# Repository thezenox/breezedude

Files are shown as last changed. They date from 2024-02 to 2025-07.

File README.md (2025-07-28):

# BreezeDude
### An Open source low power FANET wind sensor.

Map of almost all wind stations: https://breezedude.de/

For more info and docs see the [Wiki](https://github.com/thezenox/breezedude/wiki)

----
<p align="center">
  <
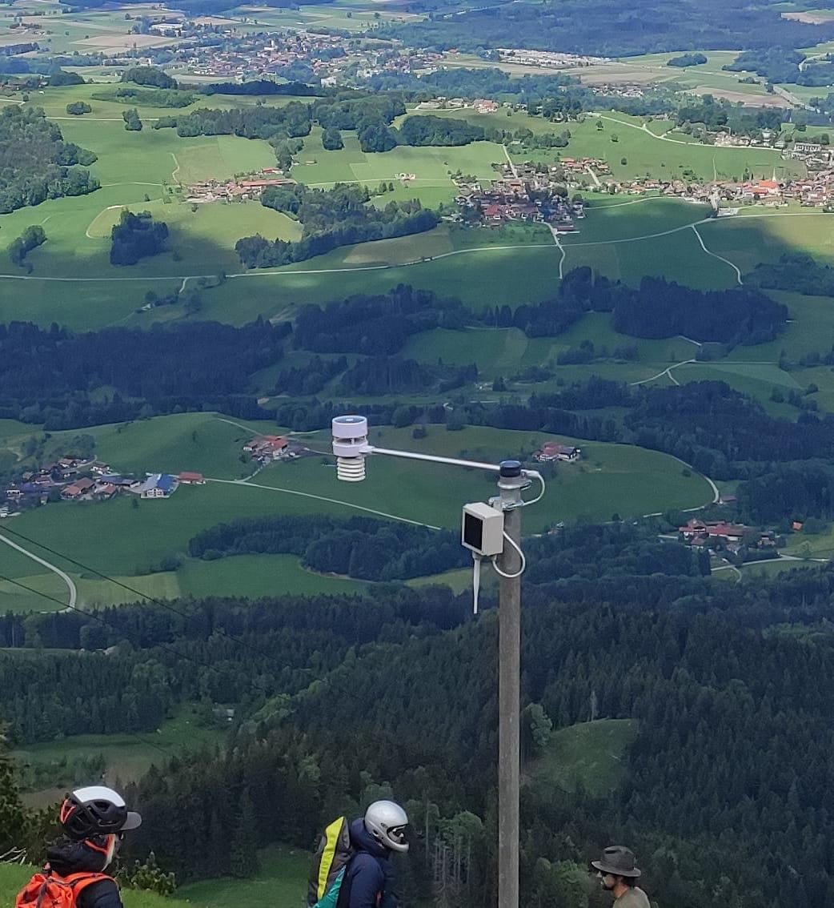
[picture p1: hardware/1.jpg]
  
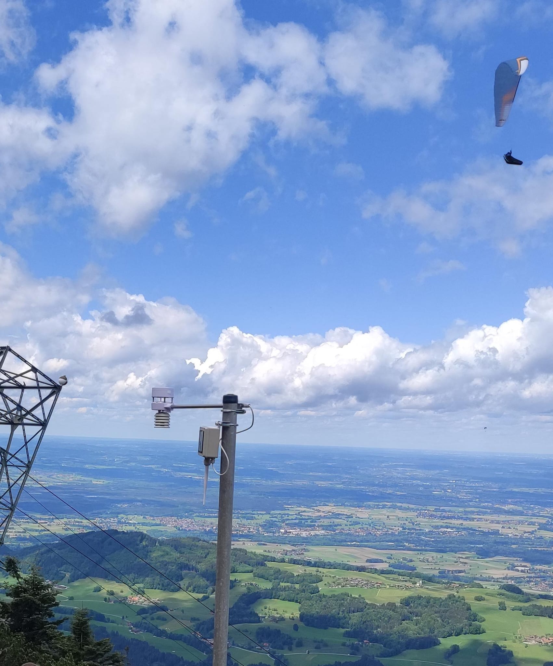
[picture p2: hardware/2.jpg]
   <br>
  <br>
</p>

A low cost FANET wind station using Ecowitt WS80/WS85 ultrasonic or DAVIS 6410 analog sensor.     
USB MSC Settings file and Drag&Drop Firmware upgrade. 

- wind sensor: Ecowitt WS80/WS85 or analog with reed/potentiometer (e.g. DAVIS 6410)
- pressure sensor: HP303B, BMP280, BMP3xx or SPL06-001
- LoRa module: RFM95W (SX1276), G-NiceRF SX1262, LLCC68
- antenna connector: SMA
- microcontroller: SAMD21
- connectivity: USB-C, I2C, 2x UART
- battery: 1S Li-Ion 16340 750mAh (or 1-3x 18650 external)
- solar: 5V
- PCB Size: 53x22mm

Currently using a 60x60 5V solar panel.     
Avg. power consumption at 40s send interval @3.7V battery: 1.2mA with analog sensor, 2.22mA with WS80
 
Based on SMAD21 using [adafruits samd core](https://github.com/adafruit/ArduinoCore-samd) and itsybitsy M0 variant definitions and [bootloader](https://github.com/adafruit/uf2-samdx1).     

#### Related projects and inspiration:
* https://github.com/gereic/GXAirCom
* https://github.com/jgromes/RadioLib
* https://github.com/3s1d/fanet-stm32

If you like this project

<a href="https://www.buymeacoffee.com/thezenox" target="_blank">Buy Me A Landingbeer</a>

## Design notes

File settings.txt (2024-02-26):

#Kommentar

NAME=Teststation

LON=12.345678
LAT=45.678901
ALT=456

HEATER=1
V_HEATER=4.5
V_MPPT=4.8

HEADING_OFFSET=0

BROADCAST_INTERVAL_WEATHER=40
BROADCAST_INTERVAL_NAME=300

SENSOR_BMP280=1
SENSOR_DAVIS6410=0
SENSOR_WS80=1

DEBUG=0
DIV_CPU_SLOW=1
WDT=0

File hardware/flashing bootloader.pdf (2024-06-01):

## Flashing bootloader on factory new SAMD21

### Prerequisites:

- AVR/Microchip Studio
- JTAG programmer (eg. Segger J-Link) + drivers installed
- SAMD21 board (ATSAMD21G18A)

### Programming:

1. Hook up SWD_IO, SWD_CLK and GND of your programmer to the board. Power the board.
2. Start Microchip Studio and open “Device Programming” in Tools.

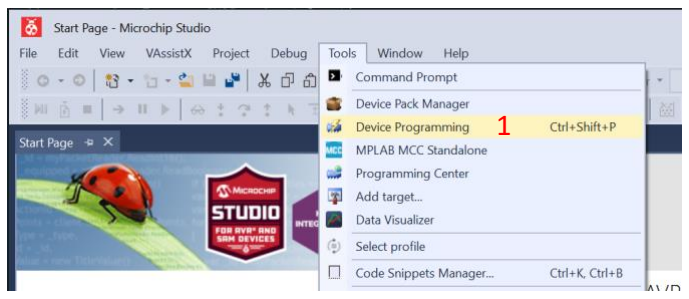
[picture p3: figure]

3. Your programmer should be listed in tools. Select the device type “ATSAMD21G18A” and klick “Apply” and “Read”. The target should be detected.

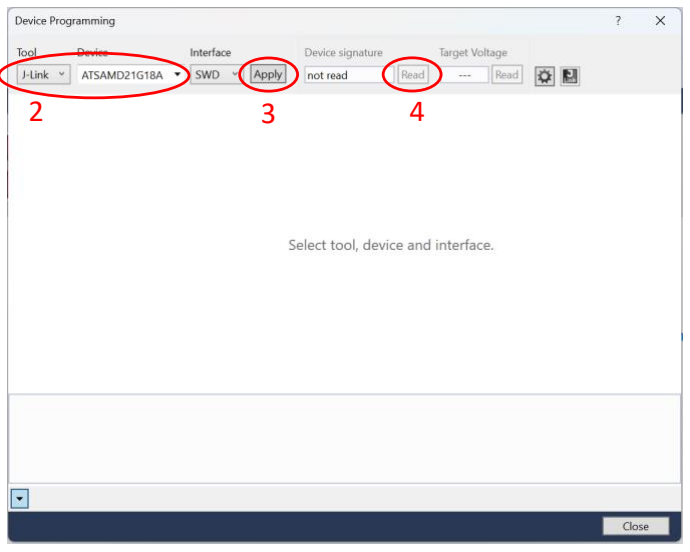
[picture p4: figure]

4. Select “Memories” and klick on “…” to select the bootloader.hex file as flash content.
5. Klick “Program” to write flash content.

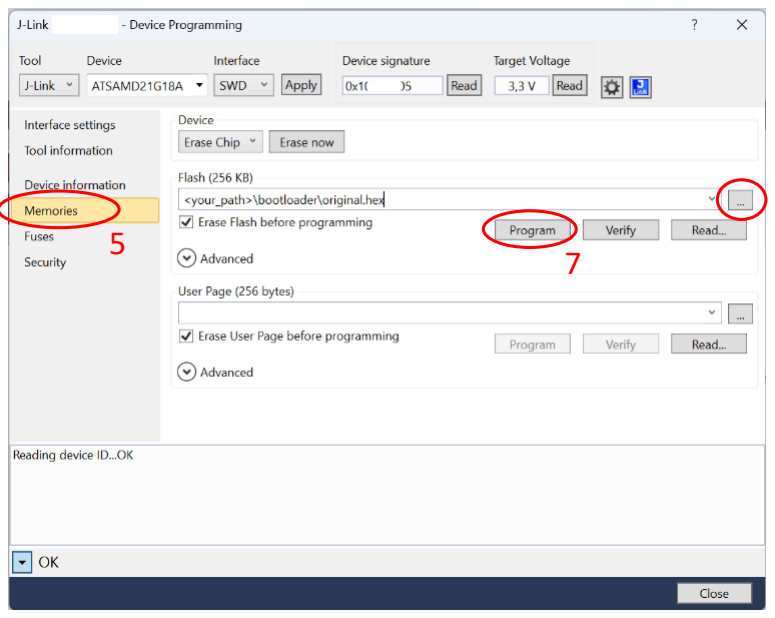
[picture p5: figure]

6. Your device now contains a bootloader capable of sam-ba and USB-MSC uf2 (drag&drop) programming. Double tap the reset button to enter USB-MSC bootloader mode.

6

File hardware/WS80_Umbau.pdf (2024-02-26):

## Modifizierung für UART Datenausgabe - Ecowitt WS80 / Froggit DP1000

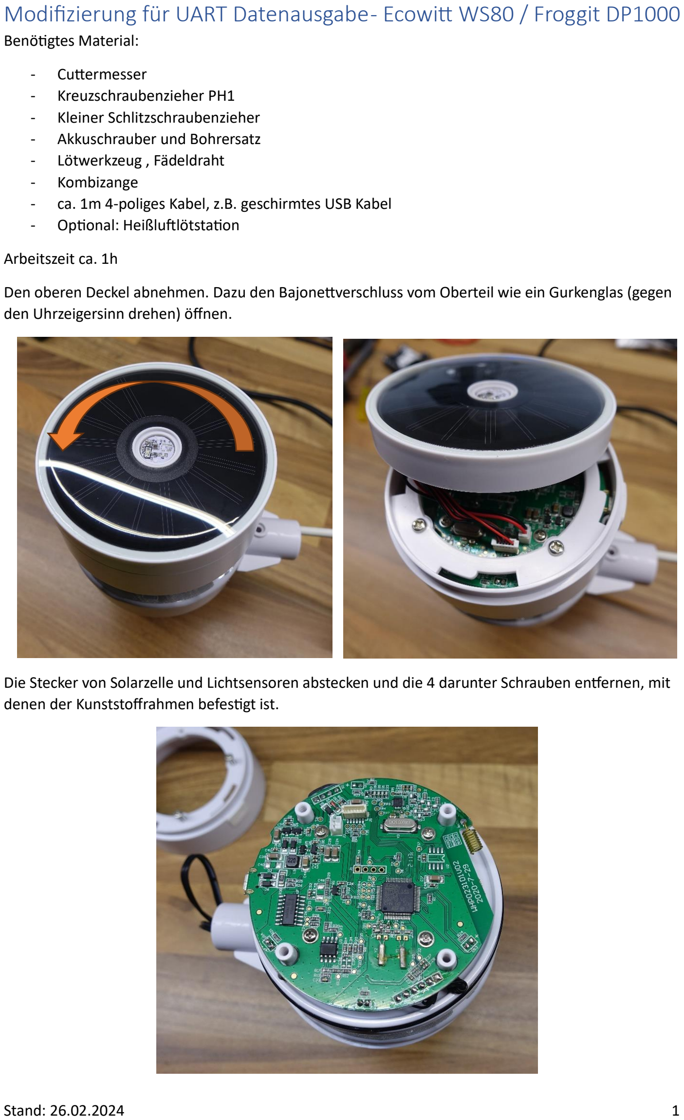
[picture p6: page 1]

Stand: 26.02.2024 | 1

Benötigtes Material:

- Cuttermesser
- Kreuzschraubenzieher PH1
- Kleiner Schlitzschraubenzieher
- Akkuschrauber und Bohrersatz
- Lötwerkzeug , Fädeldraht
- Kombizange
- ca. 1m 4-poliges Kabel, z.B. geschirmtes USB Kabel
- Optional: Heißluftlötstation

Arbeitszeit ca. 1h

Den oberen Deckel abnehmen. Dazu den Bajonettverschluss vom Oberteil wie ein Gurkenglas (gegen den Uhrzeigersinn drehen) öffnen.

Die Stecker von Solarzelle und Lichtsensoren abstecken und die 4 darunter Schrauben entfernen, mit denen der Kunststoffrahmen befestigt ist.

Optional aber empfohlen: Um unnötigen Funkverkehr/Störungen vorzubeugen und Strom zu sparen, kann das Funk-IC entfernt werden. Alternativ kann auch die Stromversorgung gekappt (Pin 4 und 7 vom CMT2300A) oder das Quarz entfernt werden.

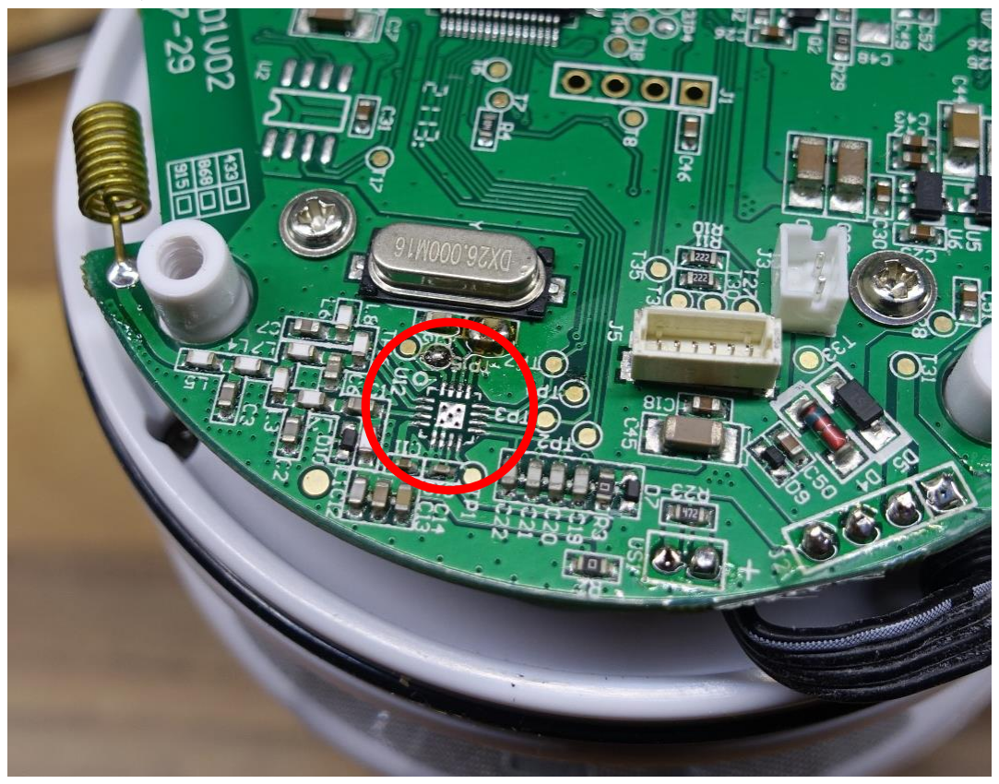
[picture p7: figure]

Um die vollständige Datenausgabe per UART zu aktivieren wird der Pulldown Widerstand R4 entfernt und stattdessen ein 10k Ohm Pullup eingebaut. Die 3.3V kann man z.B. von C31 per Kabelbrücke nehmen. Die Datenausgabe erfolgt über TP6. Diesen löten wir auf Pin 6 von U2 (vermutlich RS485 Vorbereitung) welcher mit einer freien Leitung in die Untere hälfte des Sensors verbunden ist. Dort können wir später die Datenleitung nach Draußen anschließen.

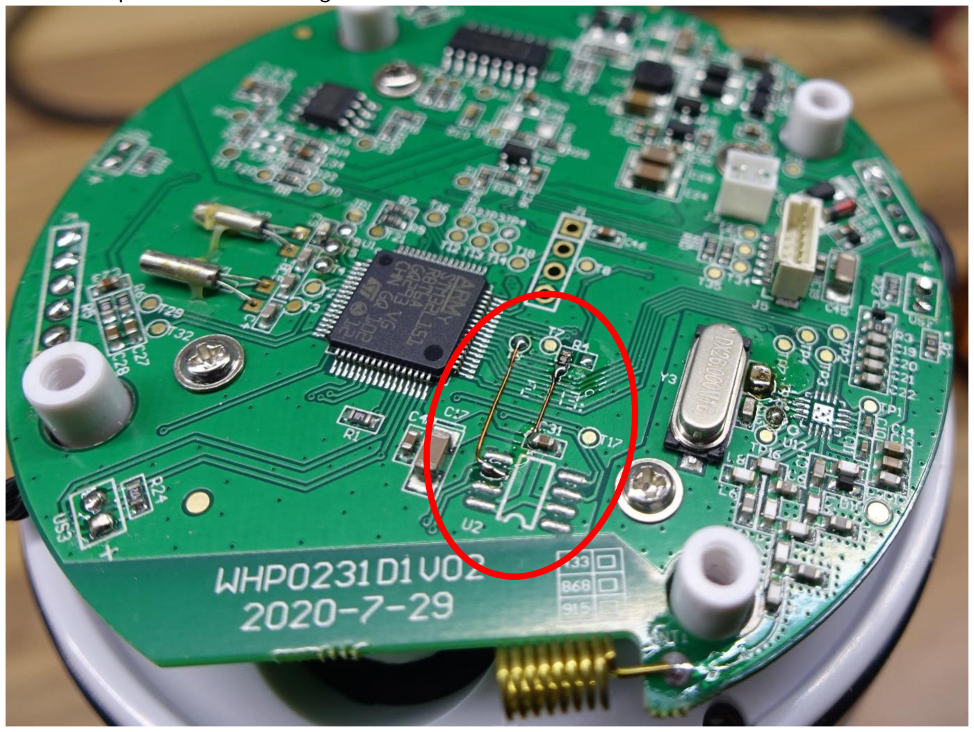
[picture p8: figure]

Nun kommt der schwierigste Teil: Die untere Hälfte ist mit Silikon verklebt. Zuerst die 4 Schrauben entfernen. Zum Öffnen mit einem Cuttermesser langsam und vorsichtig einmal rum schneiden und wenn man mit dem Messer etwas in den Schlitz rein kommt vorsichtig rundherum aufhebeln. Mit etwas Geduld und feingefühlt lässt sich das Gehäuse so ohne Spuren öffnen.

[Bild folgt]

Ist der Untere Teil offen, kann man vorsichtig die Kabel in den Stelzen von oben nachziehen, damit man mehr Bewegungsfreiheit gewinnt. Falls diese zwicken mit etwas Silikonspray nachhelfen und schauen, dass die Kabel beim Einlauf in die Stelze gut liegen.

[Bild folgt]

Nun werden die drei Schrauben der unteren Platine entfernt und die Kontakte vom Akkufach und vom Superkondensator abgelötet und die Platine herausgenommen. Das Kabel der Heizung kann nahe an der Platine abgeschnitten werden, die zweite Leitung etwa gleich lang abschneiden und das alte Kabel einfach herausziehen. Der Thermoschalter wird nicht mehr verwendet und kann entfernt werden um Platz zu gewinnen

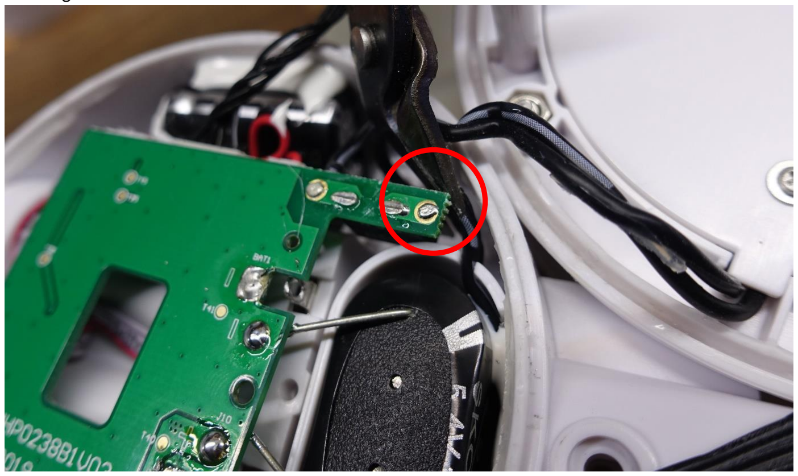
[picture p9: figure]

Um ein neues (min. 4-poliges) Kabel einzufädeln, muss der Superkondensator erstmal ausgebaut werden.

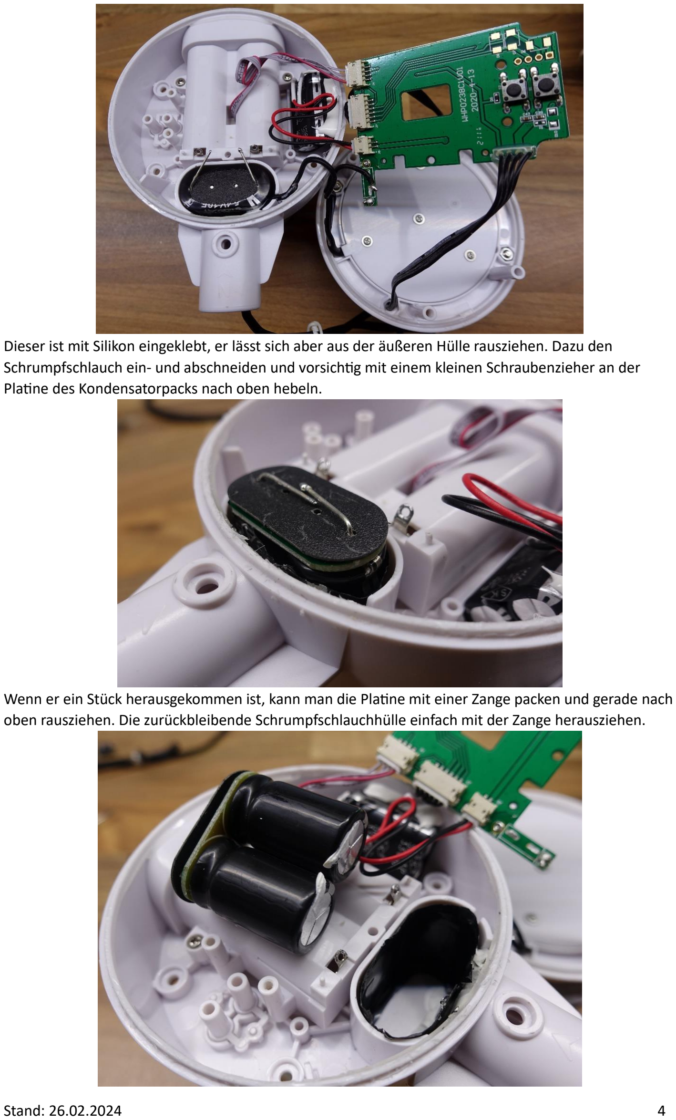
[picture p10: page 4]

Dieser ist mit Silikon eingeklebt, er lässt sich aber aus der äußeren Hülle rausziehen. Dazu den Schrumpfschlauch ein- und abschneiden und vorsichtig mit einem kleinen Schraubenzieher an der Platine des Kondensatorpacks nach oben hebeln.

Wenn er ein Stück herausgekommen ist, kann man die Platine mit einer Zange packen und gerade nach oben rausziehen. Die zurückbleibende Schrumpfschlauchhülle einfach mit der Zange herausziehen.

Jetzt kann das Loch für das neue Kabel auf den entsprechenden Durchmesser (bei mir 4.5mm) aufgebohrt werden.

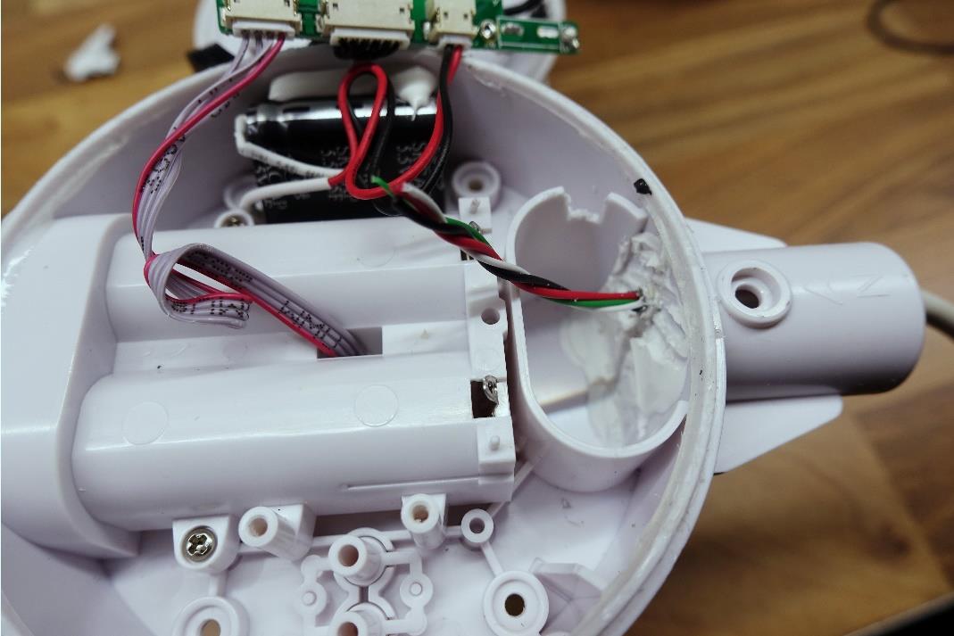
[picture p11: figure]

Die Kabel werden folgendermaßen angeschlossen:
- Eine Seite der Heizung (Polarität egal) auf Masse, die andere auf eine Ader vom neuen Kabel
- Die Datenleitung wird am Lötpad neben TP46 angeschlossen
- Die gemeinsame Masse von Versorgung und Heizung auf Masse
- Die Versorgung vom Sensor auf den alten + Kontakt vom Batteriefach

Wer ein 5-poliges Kabel verwenden möchte, kann die die Stromversorgung der Heizung komplett getrennt führen (keine gemeinsame Masseleitung).

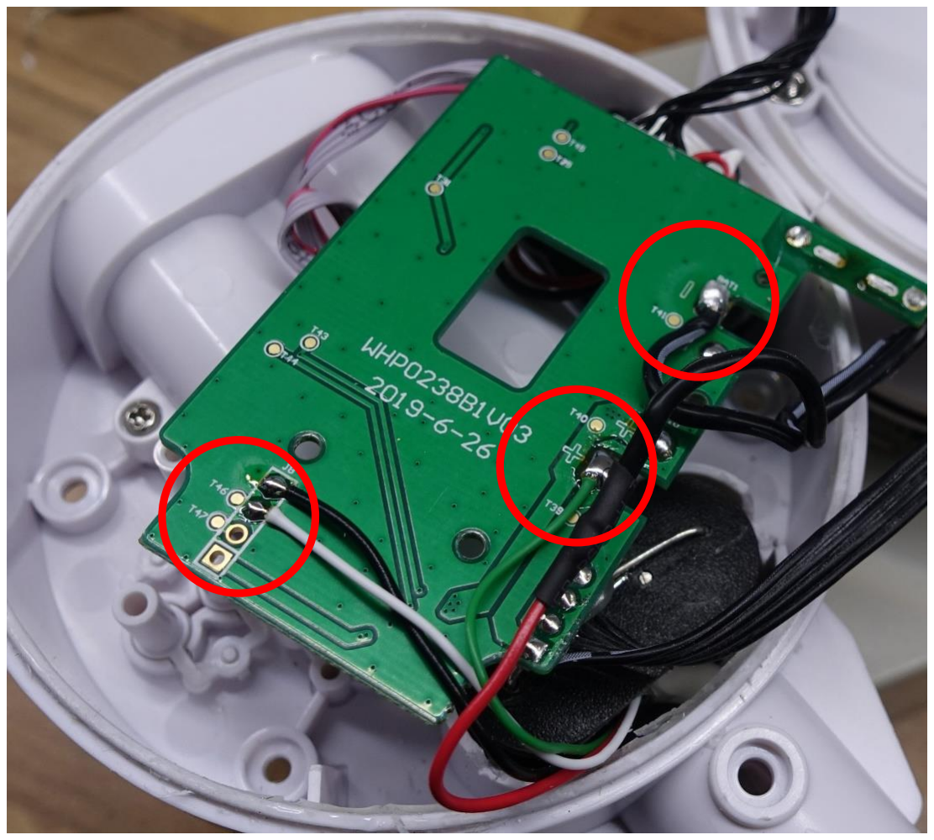
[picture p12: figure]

Anschließend alles wieder einbauen und den Kondensator wieder anlöten (Polarität beachten, Minus zu Minus). Die Kontakte vom Batteriefach werden nicht benötigt.

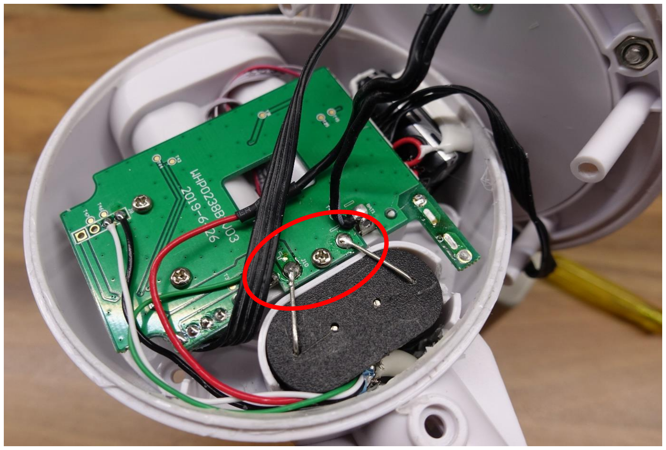
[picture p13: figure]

Jetzt die überschüssigen Kabel wieder in den Oberteil ziehen und die untere Hälfte verschließen. Wer will kann frisches Silikon zum Abdichten auftragen (ggf. vorher auf Funktion prüfen).

Die Oberseite wird einfach in umgekehrter Reihenfolge wie beim Auseinanderbau zusammengebaut. Beim Aufschieben des inneren Kunststoffrahmens ggf. etwas Fett auf die Dichtung auftragen.

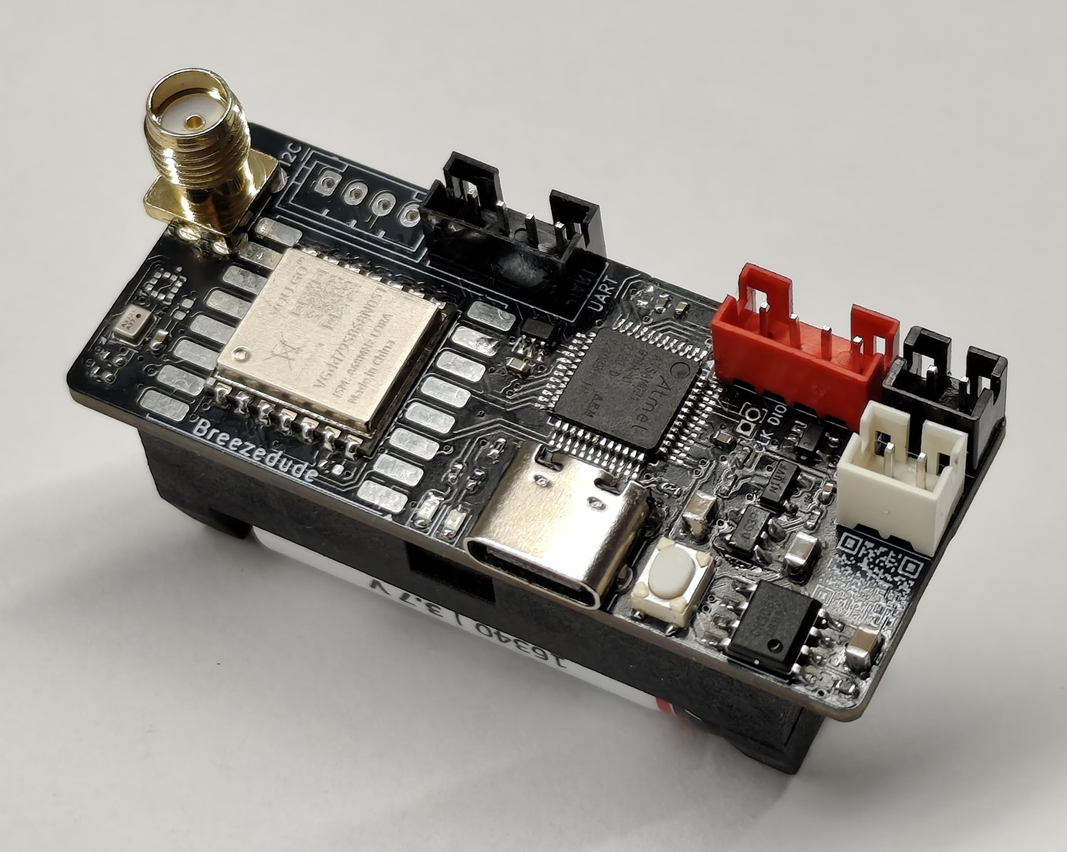
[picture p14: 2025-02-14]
hardware/mini_v2.jpg

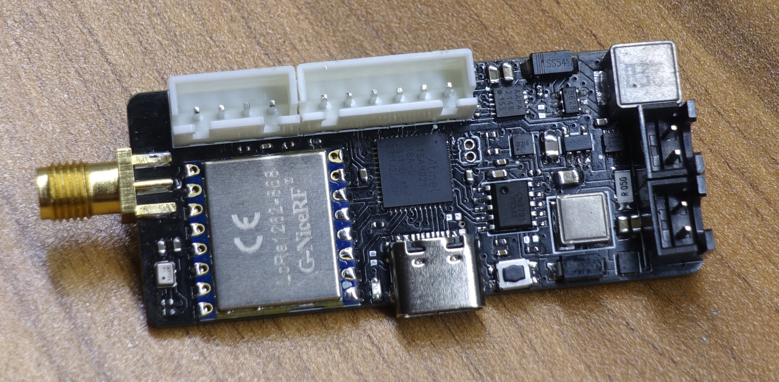
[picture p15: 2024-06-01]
hardware/pcb.png

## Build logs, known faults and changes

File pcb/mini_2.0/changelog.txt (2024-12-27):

2024-12-18: 
Mini V2.0
* Based on alpha 1.4, remade in KiCAD
* Removed heater support (DCDC)
* Changed to linear PV charger (CN 3063)
* TQPF48 package for SAMD21 (cheaper on JLCPCB, better thermal stress durability)
* TVS diodes for all external wiring
* BMP388 baro option
* Second (red) LED for error display
* Onboard battery holder for 16340 (CR123A size)

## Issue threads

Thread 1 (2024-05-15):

Embedded Rak4631 in the head.

tavdog, 2024-05-15:
Great project and good instructions!  I managed to enable serial and embed a Rak4631 in the head powered by the ws80 as well.  However the rak powered down after 24 hours.  I'm wondering if you know any more details about how the batteries and super caps work together to power the ws80.  The Rak4631 is already a very low power device so I'm hoping this can be made reliable.
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

thanks again for the great documentation.

thezenox, 2024-05-15:
I havn't electrically checked in detail yet, but the solar panel charges the super caps, if the caps fall below V_bat, the batteries kick in to keep in running. Make shure the RAK is running with 3.0V or slightly below on the input

tavdog, 2024-06-21:
My first test was a fail as the solar panel with supercaps couldn't keep the rak powered and the batteries died.

Closed 2024-06-21.

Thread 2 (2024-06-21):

WS85 test ?

tavdog, 2024-06-21:
Hi there.  I've recently gotten a WS85 which is close but not the same as the ws80.  This board hads TX and RX pads labeled on the top board.  Any idea where the enable serial output might be on this board ?
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

Thanks.

mikechristiansen, 2025-03-13:
Hey @tavdog This station can be modified per this article for the Meshtastic system.
https://hackaday.io/project/196990-meshtastic-ultrasonic-anemometer-wx-station
I believe this should make it work with this project too!
I have one of these working on meshtastic, and am hoping to use this in GxAirCom too.

tavdog, 2025-03-13:
I did end up figuring it out.  That's my article on hackaday :) hehe

Closed 2025-03-13.

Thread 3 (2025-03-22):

RAK3172 variant?

mikechristiansen, 2025-03-22:
Hi from NZ!
Ive just found your project after I had started designing my own FANET weather station.
I have been using GxAirCom with great sucess but started looking into the RAK3172 for STM32 based hardware, hoping to simplify the project and drastically reduce power consumption. Looks like you have achieved all of that here!

Im wondering if I can define a custom board in your project, and adapt it to work with the STM32WL5 that is in the RAK3172 chip. This module uses an internal SX1262 chip. Im quite a novice with coding tho, so my approch might be a little hacky!

thezenox, 2025-03-22:
85% of the work in this project is for achiving low power on SAMD21 and USB-MSC for configuration. Both won't work out of the box for the STM32WL5 (and it has no native USB neither). You can take some of the concepts and functions e.g. for packing and sending FANET frames but it would be much more than just adding a board definition.

Closed 2025-03-22.

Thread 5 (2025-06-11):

SWD connection inquiry

mhofner21, 2025-06-11:
Hi Florian,

first off, thanks a lot for your great work on this project! I’ve ordered five boards for our club and a neighboring clubs, and I’m now preparing to flash them. If everything works well, we’d likely be interested in ordering additional units.

Before I start, I’d love to ask how you establish the SWD connection on your boards:

- Did you design a custom 3D-printed jig that fits the C / D / G contacts?

- Are you using pogo pins, or is there another method you recommend for getting a reliable connection?

- Is there perhaps a commercially available connector that fits the 1.00 mm pitch header?

- If you have a setup or jig file you could share, that would be amazing.

If there’s no alternative, I would solder wires directly for the flashing process, but I’d prefer to avoid that if possible.

Also: for future hardware revisions, would it be possible to break out the SWD pins to the outside edge with a standard 2.54 mm pitch header? That would make the flashing process much easier, especially for clubs that don’t have test rigs or custom jigs.

Thanks again & best regards,
Matthias

thezenox, 2025-06-12:
I think the 3.16 bootloader from adafruit should be fine. I just changed USB & flash drive names.
update-bootloader-xxx.uf2 requires a uf2 bootloader already installed (drag&drop update of the bootloader)
for SWD flashing you require a bin or hex file.

I included the bootloader bin & current firmware as uf2. Flash the bootloader using SWD, then connect the breezedude to USB and drag&drop the firmware .uf2 file.

Closed 2025-06-13.

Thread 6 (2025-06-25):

FANET forwarding

mikechristiansen, 2025-06-25:
Hi @thezenox,
Your project has had some discussion on the GxAirCom facebook page since an article about your project was posted. It seems that many are looking for FANET message forwarding on many weather sites. Understandably running the LORA radio in RX mode will add power consumption to your project, but have you considered making this an option?
GxAirCom obviously provides for forwarding however I think the approch your project takes with power consumption has signifcant advantages.
Regards,
Mike.

thezenox, 2025-06-27:
Hi @mikechristiansen
Currently I did not consider this feature. LLCC68 consumes about 5mA in RX mode and it is possible to set an interrupt on syncword match, so MCU can be in deepsleep.
With the currently used hardware always on RX consumes to much power, but a smart mode to enable it only when surplus energy is available should be possible.
With a bigger solar cell (e.g. 130x150) and battery (min. 2x 18650) always on should be possible as well.

thezenox, 2025-06-27:
If it is just for forwarding weather stations with a fixed transmission interval you could listen to them a few times to get known the transmission interval and then turn on RX just a few seconds before. This would save 95% of power, but requires a consistent and on point TX timing of the weather station (breezedude has that, on GxAirCom it depends on traffic and neighbor count).
When Battery is full and solar is charging, continuous RX would be possible resulting in general FANET forwarding (but requires 1% limiting).
I will have a look on than the next weeks if I find time.
For the RAK enclosure: An external SMA connector is not that good, avoid it if you can.

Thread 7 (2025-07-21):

Unable to flash Breezedude boards – tried multiple setups (J-Link EDU Mini, Raspberry Pi)

mhofner21, 2025-07-21:
Hi Florian,

thanks for making the Breezedude project available to the community.

We’ve been trying to flash the microcontroller, but unfortunately without success so far. Here's a quick summary of what we've tried:

- We had several Breezedude boards produced by JLCPCB.
- I generated the Gerber files myself from the provided KiCad project, using a KiCad fabrication plugin (with default settings).
- We're using a J-Link EDU Mini for flashing, as described in the documentation.
- Unfortunately, none of the boards could be flashed – the process fails every time, and the tool doesn't seem to recognize the chip.
- As an alternative, we also tried flashing via SWD using a Raspberry Pi – same result.

We've double-checked connections, pin assignments, and voltages – everything seems to match what's documented. Could there be an issue with the current board version or with the way the KiCad files were exported? Or are we possibly missing something obvious?

If it helps, I'm happy to send you one or two of the boards by mail (via Deutsche Post) so you can take a look yourself.

I've also attached the Gerber files we used for fabrication, in case you'd like to take a quick look.
[Order-JLCPCB.zip](https://github.com/user-attachments/files/21352394/Order-JLCPCB.zip)

I understand that you can’t provide support for everything you’ve generously made available as open source – but I’d really appreciate any hints or guidance you might be able to share.

Best regards
Matthias

thezenox, 2025-07-23:
Hi Matthias
I quickly checked the images of the gerber file, seems ok, some orientations are wrong in the picture but JLC fixes that normally. All Designs in this repo should work and your Gerber generation process seems fine.

For SWD flashing only SWD and power should matter. Could you double check:
* actual orientration of the SAMD21 on the board
* conductivity of the SWD pads to the IC pins
* 3.3V on all power pins of the SAMD21

Can you test the programmer (maybe even with the same wiring harness) on a different device?
Also check for ground loops or too long wires, I once had problems with that (I use 10cm wire on the programmer)
How do you power the board during programming?

thezenox, 2025-07-28:
I did not change any fuse values. As a reference the values of a working one.
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

Can you attach a picture of the programming setup/wires? I once had the same issue with some bootloader flashing and some giving errors, I think it was a connection issue of some wire.

Here is a full flash dump of a programmed one, you can try flashing this (bootloader + firmware + config)
[working_06_12.zip](https://github.com/user-attachments/files/21463023/working_06_12.zip)

JLC will check parts orientation anyway, at least when there are errors of parts not matching the pads. But your boards look fine.

I tested open-ocd flashing and added it to the wiki. You can maybe get (or build) a cheap CMSIS-DAP programmer and try with this.

If this does not help, you can send me some boards, but I am 90% sure I can program them.

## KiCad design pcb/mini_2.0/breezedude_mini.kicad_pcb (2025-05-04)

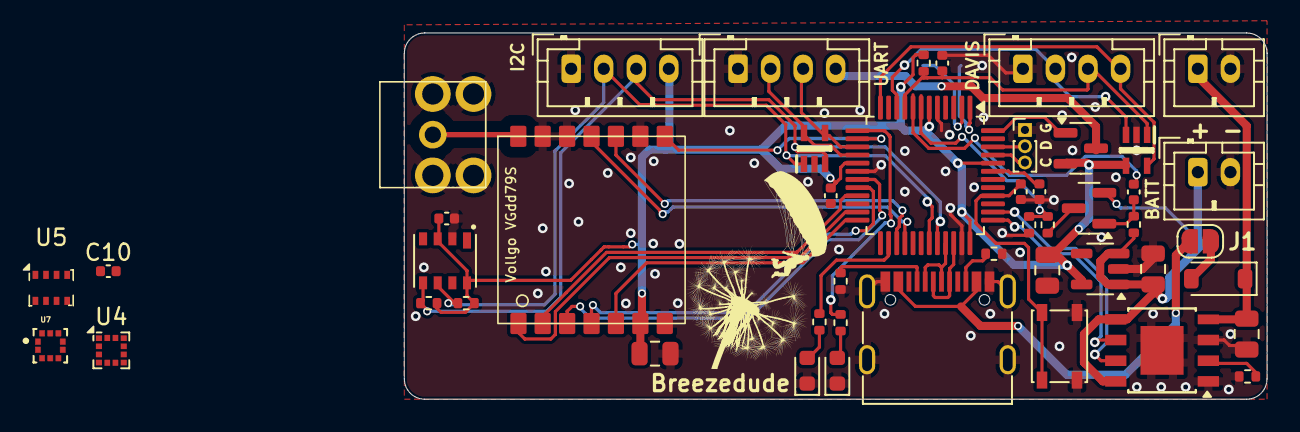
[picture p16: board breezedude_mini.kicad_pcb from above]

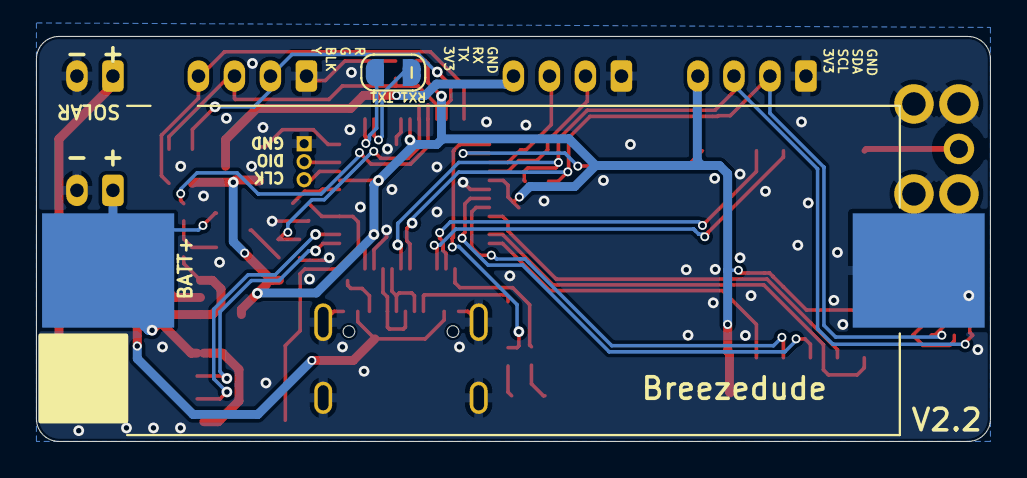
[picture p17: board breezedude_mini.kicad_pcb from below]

Board: 2 copper layers, 53.0 x 22.5 mm, 49 parts (2 on the bottom side), 46 nets.

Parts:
AE1: Antenna_Shield; sma_edge_6.5mm_vert
BT1: 1050; BAT_1050
C1, C3, C4, C12: 47u 6.3V; C_0805_2012Metric
C2, C6, C8: 10u 6.3V; C_0402_1005Metric
C5, C9, C11: 100n 16V; C_0402_1005Metric
C10: 220n 16V; C_0402_1005Metric
D1, D2: SMF3.3.TCT; SOT65P210X110-5N
D3: LED blue; LED_0603_1608Metric
D4: LED red; LED_0603_1608Metric
D5: Diode; D_SOD-123
J1, J6: Conn_01x02_Pin; JST_PH_B2B-PH-K_1x02_P2.00mm_Vertical
J2, J3, J5: Conn_01x04_Pin; JST_PH_B4B-PH-K_1x04_P2.00mm_Vertical
J4: Conn_01x03_Pin; PinHeader_1x03_P1.00mm_Vertical
J7: USB_C_Receptacle_USB2.0_16P; USB_C_Receptacle_G-Switch_GT-USB-7010ASV
J8: Conn_01x02_Pin; SolderJumper-2_Open_Gap1mm
JP1: SolderJumper_2_Open; SolderJumper-2_P1.3mm_Open_RoundedPad1.0x1.5mm
Q1, Q2: P-MOS; SOT-23
R1, R3: 10k; R_0402_1005Metric
R2, R5: 100k; R_0402_1005Metric
R4: 330k; R_0402_1005Metric
R6: 470; R_0402_1005Metric
R7: 200; R_0402_1005Metric
R8, R9: 3.3k; R_0402_1005Metric
R10, R11: 5.1k; R_0402_1005Metric
SW1: SW_Push; SW_SPST_PTS810
U1: PMIC-CN3063_SOIC8_; Infineon_PG-DSO-8-43
U2: STLQ015M33R; SOT-23-5
U3: ATSAMD21G18A-A; TQFP-48_7x7mm_P0.5mm
U4: LIS2MDL; LGA-12_2x2mm_P0.5mm
U5: BMP280; Bosch_LGA-8_2x2.5mm_P0.65mm_ClockwisePinNumbering
U6: vollgo_vgdd79s868n0s1
U7: BMP388; PQFN50P200X200X80-10N
U8: HP203B; HP203B-LGA8

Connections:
3V3: C4.2, C6.2, C8.2, C12.2, D1.4 (I/O4), J2.4, Q1.2 (S), R2.1, R8.2, R9.2, U2.5 (VOUT), U3.6 (VDDANA), U3.17 (VDDIO), U3.36 (VDDIO), U3.44 (VDDIN), U4.9 (Vdd), U4.10 (Vdd_IO), U5.2 (CSB), U5.6 (VDDIO), U5.8 (VDD), U6.6 (VCC), U7.1 (VDDIO), U7.6 (CSB), U7.10 (VDD), U8.3 (VDD), U8.8 (CSB)
/ANT: AE1.1 (A), U6.14 (ANT)
/BATT+: BT1.P, C3.2, J1.1, Q2.2 (S), R3.1, U1.5 (BAT), U1.8 (FB), U2.1 (VIN), U2.3 (EN)
/DAVIS_DIR: D1.3 (I/O3), J3.2, U3.10 (PA05)
/DAVIS_POWER: D1.5 (I/O2), J3.4, U3.12 (PA07)
/DAVIS_SPEED: C5.1, D1.1 (I/O1), J3.3, R2.2, U3.9 (PA04)
/LED1: R6.1, U3.26 (PA17)
/LED2: R7.1, U3.13 (PA08)
/LORA_CS: U3.24 (PA15), U6.5 (CS)
/LORA_DIO1: U3.27 (PA18), U6.10 (DIO1)
/LORA_DIO2: U3.28 (PA19), U6.11 (BUSY)
/LORA_DIO3: U3.14 (PA09), U6.8 (DIO3)
/LORA_MISO: U3.21 (PA12), U6.2 (MISO)
/LORA_MOSI: U3.19 (PB10), U6.3 (MOSI)
/LORA_RESET: U3.23 (PA14), U6.1 (RST)
/LORA_SCK: U3.20 (PB11), U6.4 (SCK)
/PV_CHARGE: U1.7 (~CHRG), U3.38 (PB23)
/PV_DONE: U1.6 (~DONE), U3.37 (PB22)
/RESET: C11.2, SW1.1, U3.40 (~RESET)
/RX: D2.5 (I/O2), J5.2, U3.16 (PA11)
/RX1: J8.2, U3.2 (PA01)
/SCL: D2.3 (I/O3), J2.3, R8.1, U3.32 (PA23), U4.1 (SCL/SPC), U5.4 (SCK), U7.2 (SCK), U8.5 (SCL)
/SDA: D2.1 (I/O1), J2.2, R9.1, U3.31 (PA22), U4.4 (SDA/SDI/SDO), U5.3 (SDI), U7.4 (SDI), U8.6 (SDA)
/SOLAR+: C1.2, D5.1 (K), J6.1, U1.4 (VIN)
/SWDCLK: J4.3, U3.45 (PA30)
/SWDIO: J4.2, U3.46 (PA31)
/TX: D2.4 (I/O4), J5.3, U3.15 (PA10)
/TX1: J8.1, U3.1 (PA00)
/USB_N: J7.A7 (D-), J7.B7 (D-), U3.33 (PA24)
/USB_P: J7.A6 (D+), J7.B6 (D+), U3.34 (PA25)
/V_DIV: R4.2, R5.1, U3.7 (PB08)
/V_IMP: C9.2, U3.8 (PB09)
GND: AE1.2 (Shield), BT1.N, C1.1, C2.1, C3.1, C4.1, C5.2, C6.1, C8.1, C10.2, C11.1, C12.1, D1.2 (GND), D2.2 (GND), D3.1 (K), D4.1 (K), J1.2, J2.1, J3.1, J4.1, J5.1, J6.2, J7.A1 (GND), J7.A12 (GND), J7.B1 (GND), J7.B12 (GND), J7.S1 (SHIELD), R1.2, R5.2, R10.2, R11.2, SW1.2, U1.1 (TEMP), U1.3 (GND), U1.9 (EP), U2.2 (GND), U3.5 (GNDANA), U3.18 (GND), U3.35 (GND), U3.42 (GND), U4.6 (GND), U4.8 (GND), U5.1 (GND), U5.7 (GND), U6.7 (GND), U6.9 (GND), U6.12 (GND), U6.13 (GND), U7.3 (VSS), U7.5 (SDO), U7.8 (VSS), U7.9 (VSS), U8.2 (GND)
unnamed: D3.2 (A), R6.2
unnamed: D4.2 (A), R7.2
unnamed: D5.2 (A), JP1.2 (B)
unnamed: J7.A5 (CC1), R10.1
unnamed: J7.B5 (CC2), R11.1
unnamed: J7.A4 (VBUS), J7.A9 (VBUS), J7.B4 (VBUS), J7.B9 (VBUS), JP1.1 (A)
unnamed: Q2.3 (D), R4.1
unnamed: C9.1, Q2.1 (G), R3.2
unnamed: R1.1, U1.2 (ISET)
unnamed: C2.2, U3.43 (VDDCORE)
unnamed: C10.1, U4.5 (C1)
SW_WS: Q1.1 (G), U3.48 (PB03)
VCC_WS: J5.4, Q1.3 (D)

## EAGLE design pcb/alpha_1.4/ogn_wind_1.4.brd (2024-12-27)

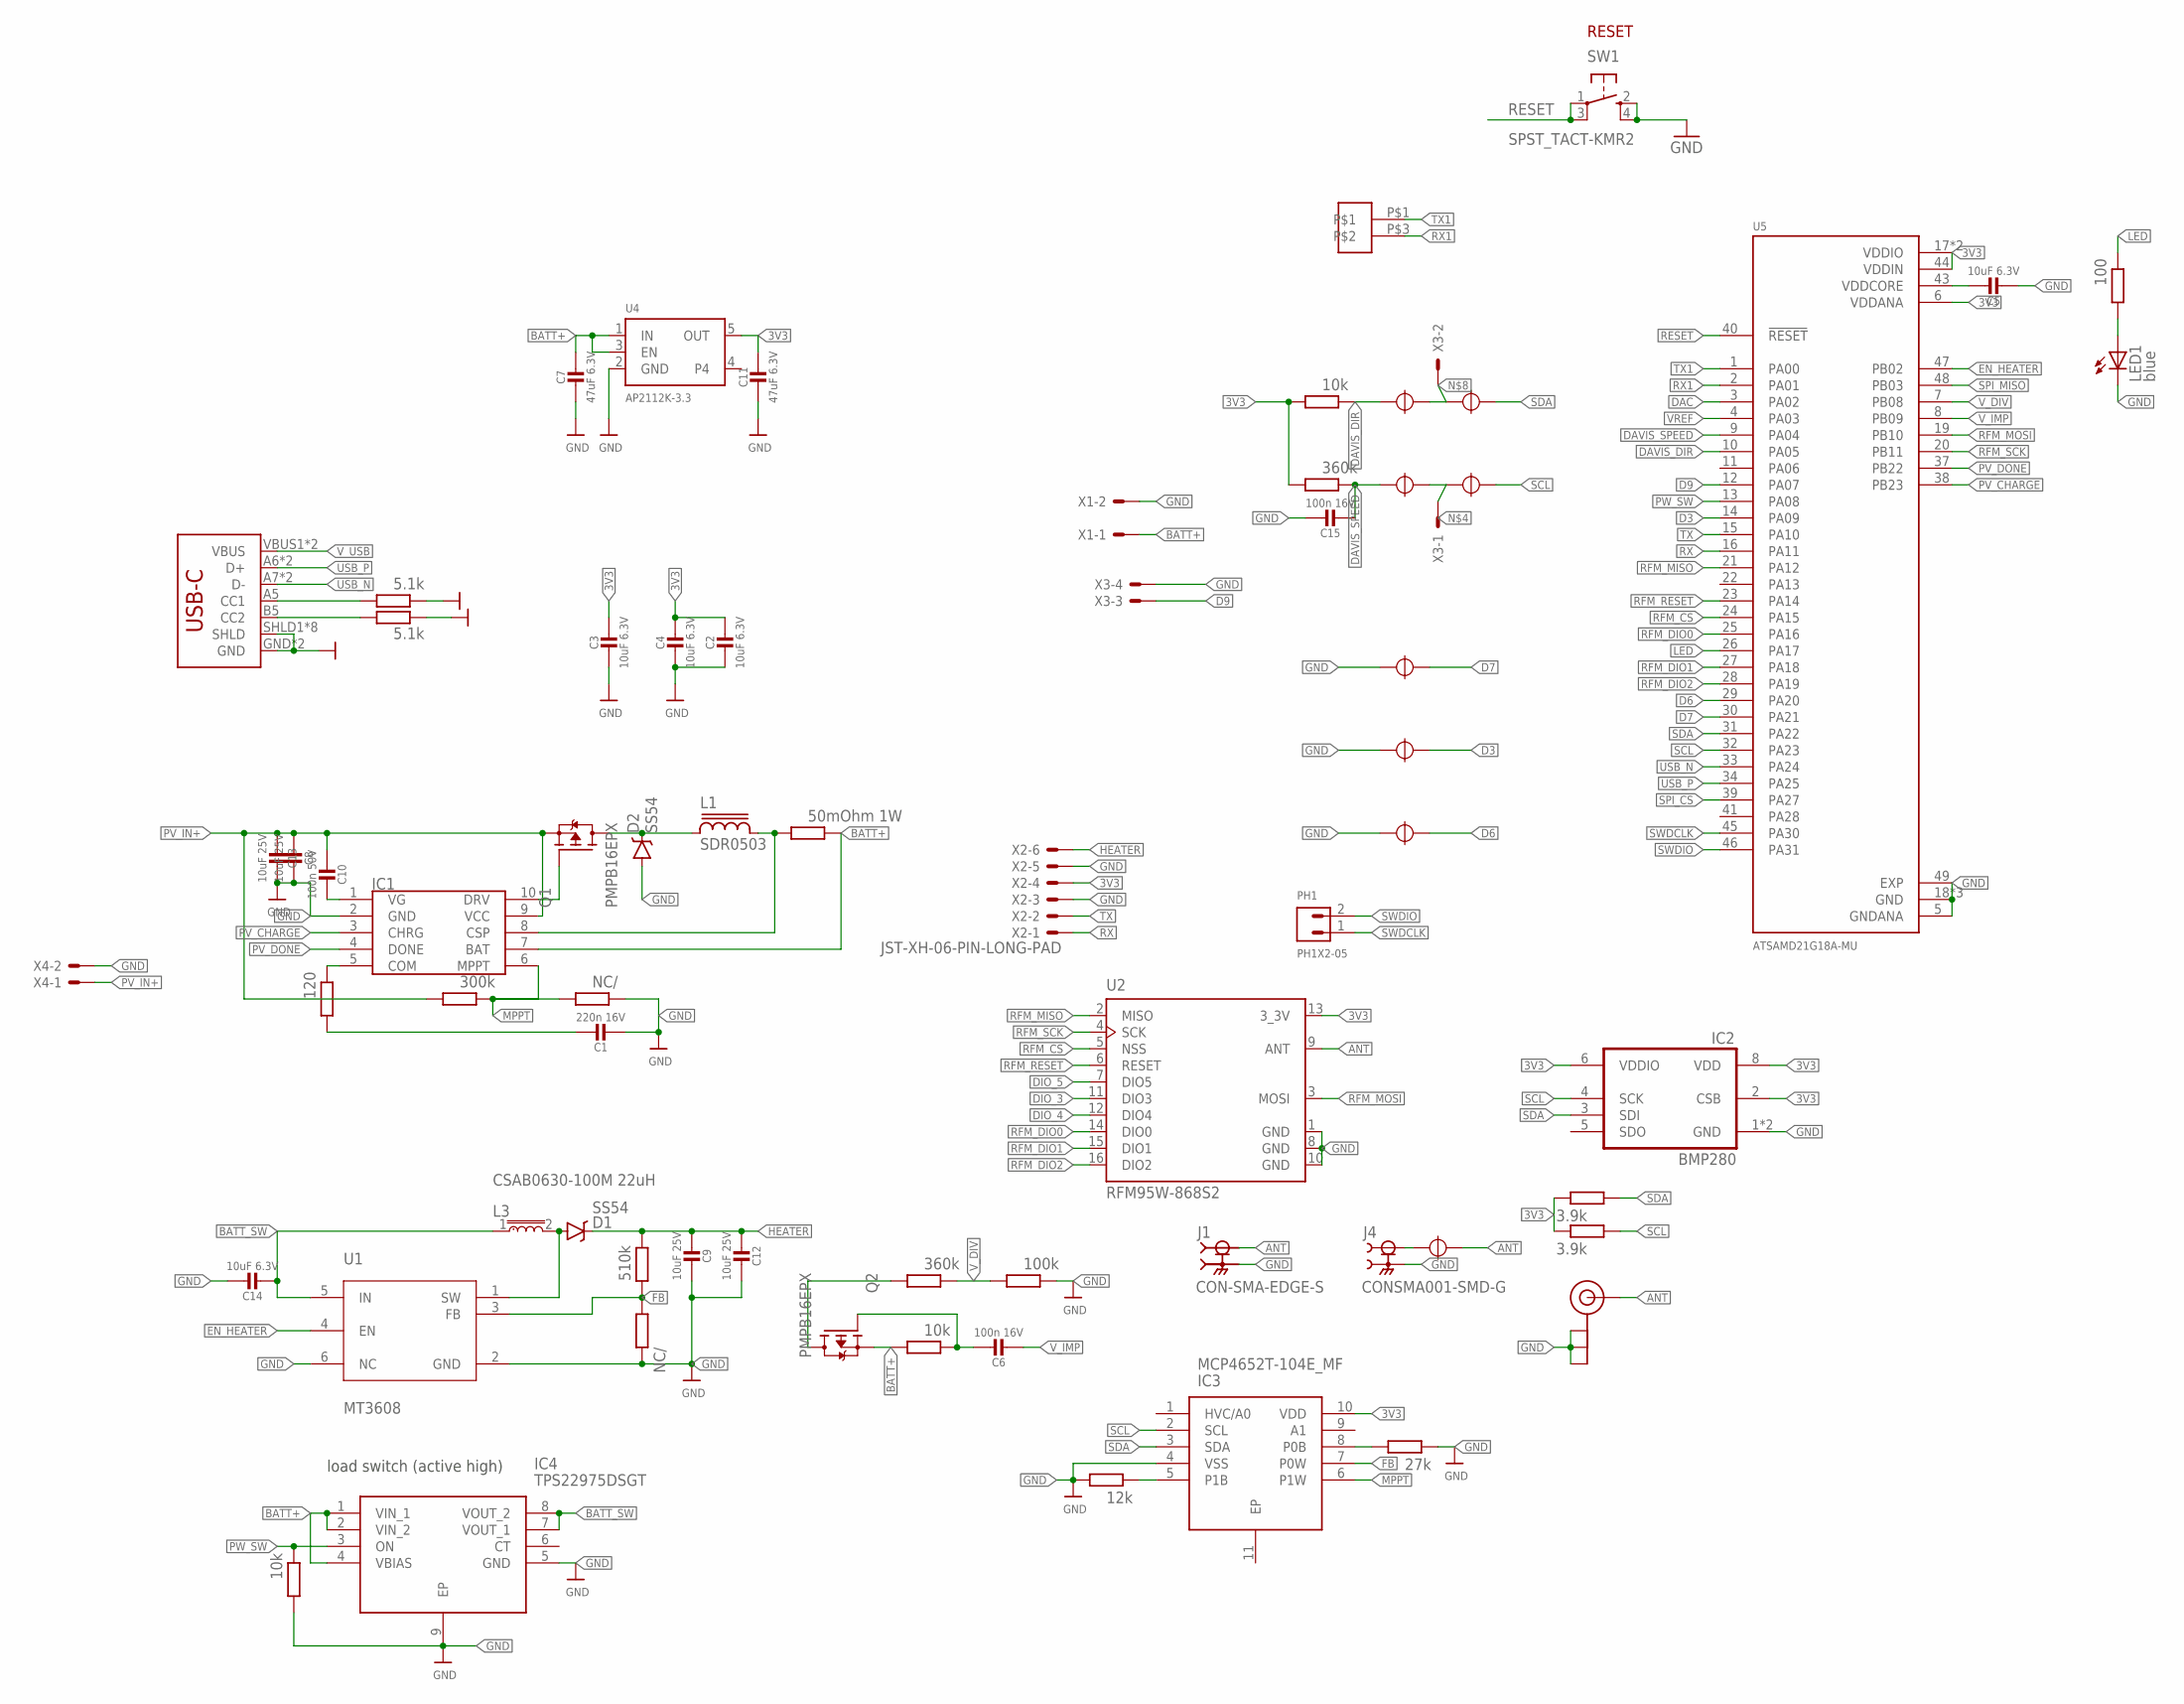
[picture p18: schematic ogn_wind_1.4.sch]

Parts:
ANT_UFL: U.FL
C1: 220n 16V; _0402MP
C2, C3, C4, C5, C14: 10uF 6.3V; _0402MP
C6, C15: 100n 16V; _0402MP
C7, C11: 47uF 6.3V; 0805-NO
C8, C9, C12, C13: 10uF 25V; _0603MP
C10: 100n 50V; _0603MP
D1, D2: SS54; DO-214AC
IC1: CN3791; SSOP10
IC2: BMP280
IC3: MCP4652T-104E_MF; SON50P300X300X100-11N
IC4: TPS22975DSGT; SON50P200X200X80-9N; JLCPCB C524777
J1: CON-SMA-EDGE-S; RFSOLUTIONS_CON-SMA-EDGE-S
J2: USB_C16PIN; USB-C-16P
J4: CONSMA001-SMD-G; LINX_CONSMA001-SMD-G
L1: SDR0503
L3: CSAB0630-100M 22uH; INDC6060X300
LED1: blue; CHIPLED_0603
PH1: PH1X2-05; PH005-1-2
Q1, Q2: PMPB16EPX; TRANS_PMPB16EPX; JLCPCB C919545
SW1: SPST_TACT-KMR2; KMR2
U1: MT3608; SOT95P280X145-6N
U2: RFM95W-868S2; XCVR_RFM95W-868S2
U4: AP2112K-3.3; SOT23-5
U5: ATSAMD21G18A-MU; QFN50P700X700X90-49N
U$1, U$2, U$3, U$4, U$7, U$10, U$11, U$22: SJ
U$13: SMDPAD2
USBCR, USBCR1: 5.1k; 0402RF
USBCR2, USBCR12: 360k; 0402RF
USBCR3: 100k; 0402RF
USBCR4, USBCR5, USBCR11: 10k; 0402RF
USBCR6: 300k; 0402RF
USBCR7, USBCR10: NC/; 0402RF
USBCR8: 120; 0402RF
USBCR9: 510k; 0402RF
USBCR13: 100; 0402RF
USBCR14, USBCR15: 3.9k; 0402RF
USBCR17: 27k; 0402RF
USBCR18: 12k; 0402RF
USBCR19: 50mOhm 1W; R1206
X1, X4: JST-XH-02-PIN-LONG-PAD; JST-XH-02-PACKAGE-LONG-PAD
X2: JST-XH-06-PIN-LONG-PAD; JST-XH-06-PACKAGE-LONG-PAD
X3: JST-XH-04-PIN-LONG-PAD; JST-XH-04-PACKAGE-LONG-PAD

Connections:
3V3: C2.1, C3.1, C4.1, C11.1, IC2.2 (CSB), IC2.6 (VDDIO), IC2.8 (VDD), IC3.10 (VDD), U2.13 (3_3V), U4.5 (OUT), U5.6 (VDDANA), U5.17 (VDDIO), U5.36 (VDDIO), U5.44 (VDDIN), USBCR11.1, USBCR12.1, USBCR14.2, USBCR15.2, X2.4
ANT: ANT_UFL.P$3 (SIGNAL), J1.1, U2.9 (ANT), U$22.P$2
BATT+: C7.1, IC1.7 (BAT), IC4.1 (VIN_1), IC4.2 (VIN_2), IC4.4 (VBIAS), Q2.4 (S), Q2.8 (S), U4.1 (IN), U4.3 (EN), USBCR4.1, USBCR19.2, X1.1
BATT_SW: C14.2, IC4.7 (VOUT_1), IC4.8 (VOUT_2), L3.1, U1.5 (IN)
D3: U5.14 (PA09), U$10.P$2
D6: U5.29 (PA20), U$11.P$2
D7: U5.30 (PA21), U$7.P$2
D9: U5.12 (PA07), X3.3
DAC: U5.3 (PA02)
DAVIS_DIR: U5.10 (PA05), U$3.P$1, USBCR11.2
DAVIS_SPEED: C15.2, U5.9 (PA04), U$1.P$1, USBCR12.2
DIO_3: U2.11 (DIO3)
DIO_4: U2.12 (DIO4)
DIO_5: U2.7 (DIO5)
EN_HEATER: U1.4 (EN), U5.47 (PB02)
FB: IC3.7 (P0W), U1.3 (FB), USBCR9.1, USBCR10.1
FB_R: IC3.8 (P0B), USBCR17.1
GND: ANT_UFL.P$1 (GND), ANT_UFL.P$2 (GND), ANT_UFL.P$4 (GND), C1.2, C2.2, C3.2, C4.2, C5.2, C7.2, C8.2, C9.1, C11.2, C12.1, C13.2, C14.1, C15.1, D2.A, IC1.2 (GND), IC2.1 (GND), IC2.7 (GND), IC3.4 (VSS), IC4.5 (GND), IC4.9 (EP), J1.G1 (2), J1.G2 (2), J1.G3 (2), J1.G4 (2), J2.GND, J2.GND2 (GND), J2.SHLD1 (SHLD), J2.SHLD2 (SHLD), J2.SHLD3 (SHLD), J2.SHLD4 (SHLD), J2.SHLD5 (SHLD), J2.SHLD6 (SHLD), J2.SHLD7 (SHLD), J2.SHLD8 (SHLD), J4.S1 (2), J4.S2 (2), LED1.C, SW1.2 (S), SW1.4 (S1), U1.2 (GND), U1.6 (NC), U2.1 (GND), U2.8 (GND), U2.10 (GND), U4.2 (GND), U5.5 (GNDANA), U5.18 (GND), U5.35 (GND), U5.42 (GND), U5.49 (EXP), U$7.P$1, U$10.P$1, U$11.P$1, USBCR.2, USBCR1.2, USBCR3.2, USBCR5.1, USBCR7.2, USBCR10.2, USBCR17.2, USBCR18.1, X1.2, X2.3, X2.5, X3.4, X4.2
HEATER: C9.2, C12.2, D1.C, USBCR9.2, X2.6
LED: U5.26 (PA17), USBCR13.2
MPPT: IC1.6 (MPPT), IC3.6 (P1W), USBCR6.2, USBCR7.1
MPPT_R: IC3.5 (P1B), USBCR18.2
unnamed: IC1.10 (DRV), Q1.3 (G)
unnamed: D2.C, L1.1, Q1.1 (D), Q1.2 (D), Q1.5 (D), Q1.6 (D), Q1.7 (D)
unnamed: IC1.8 (CSP), L1.2, USBCR19.1
unnamed: U$1.P$2, U$2.P$1, X3.1
unnamed: LED1.A, USBCR13.1
unnamed: Q2.1 (D), Q2.2 (D), Q2.5 (D), Q2.6 (D), Q2.7 (D), USBCR2.1
unnamed: C10.1, IC1.1 (VG)
unnamed: U$3.P$2, U$4.P$1, X3.2
unnamed: J4.1, U$22.P$1
unnamed: C1.1, USBCR8.1
unnamed: IC1.5 (COM), USBCR8.2
unnamed: C6.1, Q2.3 (G), USBCR4.2
unnamed: J2.A5 (CC1), USBCR.1
unnamed: J2.B5 (CC2), USBCR1.1
PV_CHARGE: IC1.3 (CHRG), U5.38 (PB23)
PV_DONE: IC1.4 (DONE), U5.37 (PB22)
PV_IN+: C8.1, C10.2, C13.1, IC1.9 (VCC), Q1.4 (S), Q1.8 (S), USBCR6.1, X4.1
PW_SW: IC4.3 (ON), U5.13 (PA08), USBCR5.2
RESET: SW1.1, SW1.3 (P1), U5.40 (!RESET)
RFM_CS: U2.5 (NSS), U5.24 (PA15)
RFM_DIO0: U2.14 (DIO0), U5.25 (PA16)
RFM_DIO1: U2.15 (DIO1), U5.27 (PA18)
RFM_DIO2: U2.16 (DIO2), U5.28 (PA19)
RFM_MISO: U2.2 (MISO), U5.21 (PA12)
RFM_MOSI: U2.3 (MOSI), U5.19 (PB10)
RFM_RESET: U2.6 (RESET), U5.23 (PA14)
RFM_SCK: U2.4 (SCK), U5.20 (PB11)
RX: U5.16 (PA11), X2.1
RX1: U5.2 (PA01), U$13.P$3
SCL: IC2.4 (SCK), IC3.2 (SCL), U5.32 (PA23), U$2.P$2, USBCR15.1
SDA: IC2.3 (SDI), IC3.3 (SDA), U5.31 (PA22), U$4.P$2, USBCR14.1
SPI_CS: U5.39 (PA27)
SPI_MISO: U5.48 (PB03)
SW: D1.A, L3.2, U1.1 (SW)
SWDCLK: PH1.1, U5.45 (PA30)
SWDIO: PH1.2, U5.46 (PA31)
TX: U5.15 (PA10), X2.2
TX1: U5.1 (PA00), U$13.P$1
USB_N: J2.A7 (D-), J2.B7 (D-), U5.33 (PA24)
USB_P: J2.A6 (D+), J2.B6 (D+), U5.34 (PA25)
VDDCORE: C5.1, U5.43 (VDDCORE)
VREF: U5.4 (PA03)
V_DIV: U5.7 (PB08), USBCR2.2, USBCR3.1
V_IMP: C6.2, U5.8 (PB09)
V_USB: J2.VBUS1 (VBUS), J2.VBUS2 (VBUS)

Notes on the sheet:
RESET
load switch (active high)

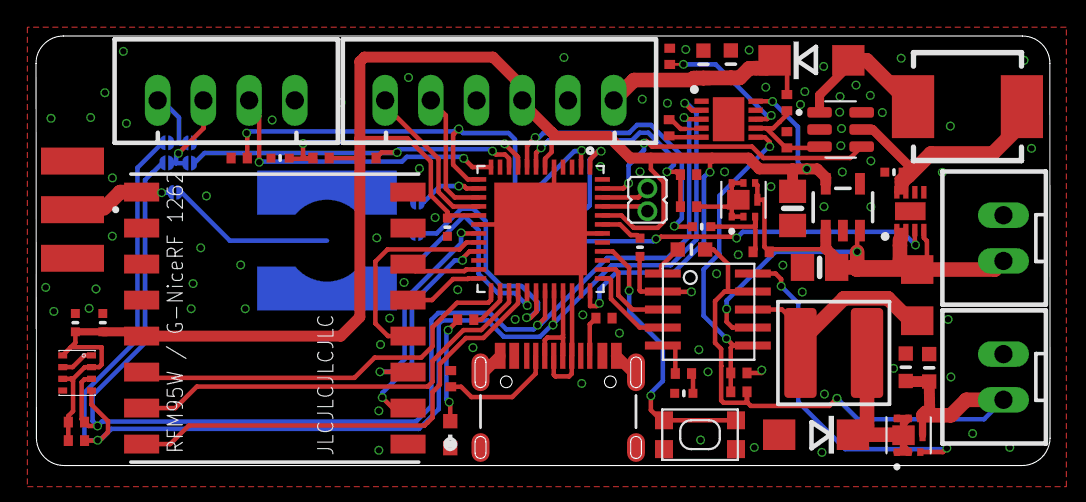
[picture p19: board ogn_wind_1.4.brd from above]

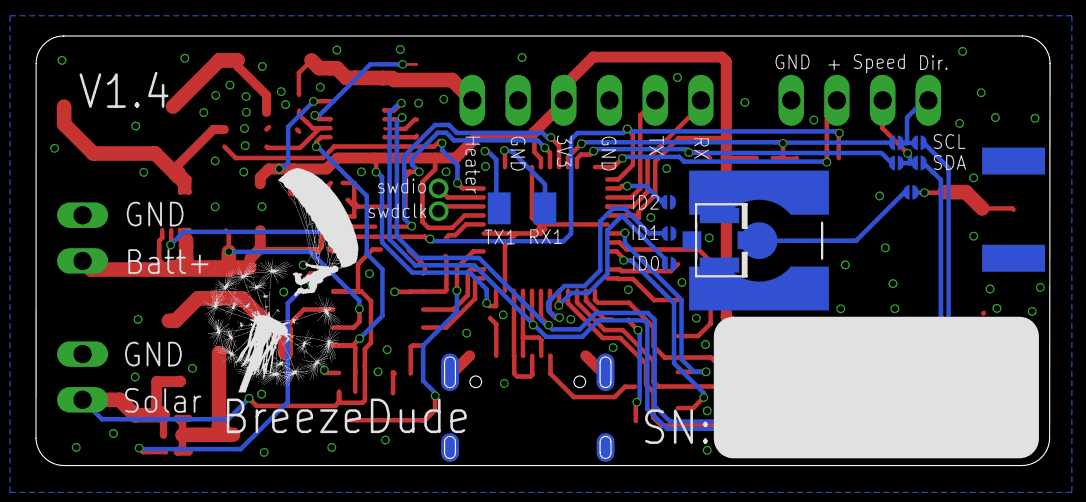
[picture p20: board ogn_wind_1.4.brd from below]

Board: 2 copper layers, 56.3 x 23.9 mm, 68 parts (11 on the bottom side), 60 nets.

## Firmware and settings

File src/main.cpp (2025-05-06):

#include <Arduino.h>
#include <Adafruit_TinyUSB.h>
#include <Wire.h>
#include <BMP280.h>
#include <HP203B.h> // https://github.com/ncdcommunity/Arduino_Library_HP203B_Barometer_Altimeter_Sensor/tree/master
#include <SPL06.h>
#include <Adafruit_BMP3XX.h>
#include <LibPrintf.h>
#include <RadioLib.h>
#include <SdFat.h>
#include <SAMD_InternalFlash.h>
#include <TinyGPS++.h>
#include <ArduinoUniqueID.h>

#include "ff.h"
#include "diskio.h"
#include "logging.h"
#include "sleep.h"
#include "types.h"
#include "display.h"
#include "hist.h"

 #define HAS_HEATER // support for Heater (HW V1.x)

// Todo list:
// * Read bootloader version
// * detect sensor frozen?

// https://github.com/adafruit/Adafruit_TinyUSB_Arduin
// https://github.com/adafruit/ArduinoCore-samd
// https://github.com/Mollayo/SAMD_InternalFlash
// https://github.com/Microsoft/uf2
// https://github.com/adafruit/uf2-samdx1

//Modifications:
// SAMD_InternalFlash.cpp:  
// use last 40kb of flash as FAT12 disk for settings file
//    _flash_address = (0x00040000 - 256 - 0 - INTERNAL_FLASH_FILESYSTEM_SIZE)

// Improvements
// LDO: 
// STLQ015M33R 1,5µA (150mA max)

//Power consumption:
// Deepsleep 180µA (without WS80 sensor, davis speed and dir open)
// avg @40s send interval: 650µA (with davis 6410)
// avg @40s send interval: 2.25mA (with WS80 1.2.8)

#define FANET_VENDOR_ID 0xBD
#define VBATT_LOW 3.35 // Volt

Adafruit_USBD_MSC usb_msc;
#define DISK_BLOCK_SIZE 512 // Block size in bytes for tinyUSB flash drive. Should be always 512

InternalFlash my_internal_storage;
Adafruit_FlashTransport_InternalFlash flashTransport(&my_internal_storage);
Adafruit_InternalFlash_Wrapper flash(&flashTransport);
FatFileSystem fatfs;
TinyGPSPlus tinyGps;

#define BROADCAST_INTERVAL 40*1000UL // dafault value,  overwritten by settingfile

#define DEBUGSER Serial1
#define WSXX_UART Serial1
#define GPS_SERIAL Serial1 // if no WS80 is connected a GPS receiver can be used. Mainly for OGN range/coverage check

// https://github.com/adafruit/ArduinoCore-samd/blob/master/variants/itsybitsy_m0/variant.cpp
// 0 { PORTA, 11, PIO_SERCOM, (PIN_ATTR_DIGITAL), No_ADC_Channel, NOT_ON_PWM, NOT_ON_TIMER, EXTERNAL_INT_11 }, // RX: SERCOM0/PAD[3]
// 1 { PORTA, 10, PIO_SERCOM, (PIN_ATTR_DIGITAL), No_ADC_Channel, NOT_ON_PWM, NOT_ON_TIMER, EXTERNAL_INT_10 }, // TX: SERCOM0/PAD[2]

// SERCOM 4 - SPI RFM95W LoRa
#define PIN_LORA_MISO MISO  // 28 PA12  - SERCOM2/PAD[0] | alt SERCOM4/PAD[0]
#define PIN_LORA_MOSI MOSI  // 29 PB10  -                | alt SERCOM4/PAD[2]
#define PIN_LORA_SCK SCK    // 30 PB11  -                | alt SERCOM4/PAD[3]

#define PIN_LORA_CS 5    // PA15 - SERCOM2/PAD[3] | alt SERCOM4/PAD[3]
#define PIN_LORA_RESET 2 // PA14 - SERCOM2/PAD[2] | alt SERCOM4/PAD[2]
#define PIN_LORA_DIO0 11 // PA16 - SERCOM1/PAD[0] | alt SERCOM3/PAD[0]
#define PIN_LORA_DIO1 10 // PA18 - SERCOM1/PAD[2] | alt SERCOM3/PAD[2]
#define PIN_LORA_DIO2 12 // PA19 - SERCOM1/PAD[3] | alt SERCOM3/PAD[3]
#define PIN_LORA_DIO3 3  // PA09 - SERCOM0/PAD[1], ADC
#define PIN_PV_CHARGE 38// PB23
#define PIN_PV_DONE 37 // PB22
#define PIN_PS_WS 36 // PB03 PIO_SERCOM_ALT, PIN_ATTR_NONE, No_ADC_Channel, NOT_ON_PWM, NOT_ON_TIMER, EXTERNAL_INT_NONE },  // SPI Flash MISO on ItsyBitsy M0, Power switch control for WSXX Sensor. HW >= 2.2

#define PIN_SERCOM1_TX 40 // PA00 SERCOM1 PAD0
#define PIN_SERCOM1_RX 10 // PA01 SERCOM1 PAD1

// Pins with solder jumpers 
#define PIN_ID0 6 // PA20 - SERCOM5/PAD[2]
#define PIN_ID1 7 // PA21 - SERCOM5/PAD[3]


// Serial2 for Degugging on HW > 1.3
Uart Serial2(&sercom1, PIN_SERCOM1_RX, PIN_SERCOM1_TX, SERCOM_RX_PAD_1, UART_TX_PAD_0 ) ;

#ifdef HAS_HEATER
  #define HEATER_MAX_V 9.20 // Maximum setpoint voltage, thermal limit by inductor (~1,8A conntiniuos, actual voltage ~8V)
  #define PIN_EN_DCDC 19 // A5 19 PB02
  #define PIN_EN_HEATER 4 //D4/A8 PA08
#endif


#define PIN_DAVIS_SPEED 17 // A3 17 PA04
#define PIN_DAVIS_DIR 18 // A4 18 PA05
#define PIN_DAVIS_POWER 9 // 9 PA07 - power for direction potentiometer. Turn off if not used to save power

// SERCOM 3 - I²C Barometer / Digipot
#define PIN_SDA 26 // PA22
#define PIN_SCL 27 // PA23

// I2C Barometer
BMP280 bmp280; // Bosch BMP280
SPL06 spl; // Goertek SPL06-001
HP203B hp; // HP203B 0x76 or 0x77
Adafruit_BMP3XX bmp3xx;
// DPS310 as alternative?

// DAVIS6410 Pinout
// Black - Wind speed contact (closure to ground)
// Red - Ground
// Green - Wind direction pot wiper (20KΩ potentiometer)
// Yellow - Pot supply voltage

// SERCOM 0 - uart serial Sensor/ GPS / Debug
#define PIN_RX 0 // A6 PA11
#define PIN_TX 1 // A7 PA10

#define PIN_STATUSLED 13 // PA17 // blue, 1.2mA @ 2.77V = 470Ohm
#define PIN_ERRORLED 4 //D4/A8 PA08 // red 2.9mA @ 2.16V = 390Ohm
#define PIN_V_READ_TRIGGER A2 // D16 PB09
#define PIN_V_READ A1 // D15 PB08 - { PORTB,  8, PIO_ANALOG, (PIN_ATTR_PWM|PIN_ATTR_TIMER), ADC_Channel2, PWM4_CH0, TC4_CH0, EXTERNAL_INT_8 }, // ADC/AIN[2]

#define VERSIONFILE (char*) "version.txt"
#define SETTINGSFILE (char*) "settings.txt"


#define MCP4652_I2C_ADDR	0x2F
#define WRITE_WIPER_DCDC	(0b0000<<4) // Wiper 0 = DCDC
#define WRITE_WIPER_MPPT	(0b0001<<4) // Wiper 1 = MPPT
#define WRITE_TCON	(0b0100<<4)
#define CMD_WRITE	(0b00<<2)

#define LORA_SYNCWORD 0xF1 //SX1262: 0xF4 0x14 https://blog.classycode.com/lora-sync-word-compatibility-between-sx127x-and-sx126x-460324d1787a is handled by RadioLib

SX1276 radio_sx1276 = new Module(PIN_LORA_CS, PIN_LORA_DIO0, PIN_LORA_RESET, PIN_LORA_DIO1);
SX1262 radio_sx1262 = new Module(PIN_LORA_CS, PIN_LORA_DIO1, PIN_LORA_RESET, PIN_LORA_DIO2);
LLCC68 radio_llcc68 = new Module(PIN_LORA_CS, PIN_LORA_DIO1, PIN_LORA_RESET, PIN_LORA_DIO2);

PhysicalLayer* radio_phy = nullptr;
bool transmittedFlag = false;

// Pulsecounter
volatile uint32_t pulsecount =0; // pulses from wind speed sensor using reed switch

// WDT and CPU Clock
#define WDT_PERIOD 2500 // ms for wdt to wait to reset mcu if not reset in time
bool use_wdt = false; // use watchdog reset
int div_cpu = 1; // current div
int div_cpu_fast = 1; // fast CPU clock 1= 48Mhz/1
int div_cpu_slow = 1; // if > 1, cpu clocks down by 48/n Mhz

bool first_sleep = true; // first sleep after reset, USB perephial could still be on
bool usb_connected = false;

uint32_t sleep_allowed = 0; // time() when is is ok so eenter deepsleep
uint32_t sleeptime_cum = 0; // cumulative time spend in sleepmode, used for time() calculation
int heading_offset = 0;

// ### Variables for storing settings from file, may be overewritten #####
String station_name="";
float pos_lat = 0;
float pos_lon = 0;
float altitude = -1;

#ifdef HAS_HEATER
  bool is_heater = false;
  float mppt_voltage = 5.5;
  float heater_voltage = 4.5;
  uint32_t heater_on_time_cum = 0;
  #define MAX_HEAT_TIME 30*60*1000UL //30 minv
#endif
bool use_mcp4652 = true; // used on first version of PCB (<=1.3) to set MPPT and DCDC voltage

enum ResParseChar {
  RESP_OK,
  RESP_ERROR,
  RESP_COMPLETE
};

enum HW_Version{
  HW_unknown,
  HW_1_3,
  HW_2_0
};

HW_Version hw_version = HW_unknown;

enum LORA_MODULE{
  LORA_NONE,
  LORA_SX1276,
  LORA_SX1262,
  LORA_LLCC68
};

LORA_MODULE lora_module = LORA_NONE;

enum BARO_CHIP{
  BARO_NONE,
  BARO_BMP280,
  BARO_SPL06,
  BARO_BMP3xx,
  BARO_HP203B
};

// Sensor selction
bool undervoltage = false;
float reduce_interval_voltage = 3.5; // below this voltage the send inverval will be reduced to save energy
bool reduced_interval = false; // reduced interval active
bool is_wsxx = false; // generic for both
bool is_ws80 = false;
bool is_ws85 = false;
bool is_davis6410 = false;
uint32_t sensor_integration_time = 12000; // ms to sleep while counting pulses. Resolution of gust detection
bool is_baro = false;
bool is_gps = false;
uint32_t last_gps_valid = 0;
bool testmode = false; // send without weather station to check lora coverage
uint32_t gps_baud = 9600;
BARO_CHIP baro_chip = BARO_NONE;
uint32_t wind_age = WIND_AGE; 
uint32_t gust_age = GUST_AGE;

bool settings_ok = false;
uint32_t next_baro_reading = 0;

// Message timing
uint32_t broadcast_interval_weather = BROADCAST_INTERVAL;
uint32_t last_msg_weather = 0;
uint32_t broadcast_interval_name = 1000*60*5; // 5 min
uint32_t last_msg_name = 0;
uint32_t broadcast_interval_info = 0;
uint32_t last_msg_info = 0;
uint32_t broadcast_scale_factor = 1; // multiplier for broadcast values. is set to 2..5 if battery is low

uint32_t last_wsxx_data = 0;
uint32_t last_fnet_send = 0; // last package send
uint32_t fanet_cooldown = 4000;
uint32_t loopcounter = 0;

// debugging
bool test_with_usb = false;
bool no_sleep = false;
bool test_heater = false;
bool debug_enabled = true; // enable uart debug messages
bool errors_enabled = true;
bool forward_serial_while_usb = false;
bool skip_lora = false; // skip lora module init

// Measurement values
float baro_pressure = 0;
float baro_temp = 0; // temp from bmp280, inside case/on pcb
int wind_dir_raw = 0;
int wind_heading = 0;
float wind_speed = 0;
float wind_gust = 0;
float temperature = 0;
int humidity = 0;
int light_lux = 0;
float uv_level = 0;
float wsxx_vcc = 0;
float cap_voltage = 0; // WS85 supercap voltage
float batt_volt = 0;
int batt_perc = 0;


#define WAKEUP_NONE 0
#define WAKEUP_RTC 1
#define WAKEUP_EIC 2
#define WAKEUP_WDT 3
int wakeup_source = WAKEUP_NONE;
const char* wakeup_source_string [4] = {"NONE", "RTC", "EIC", "WDT"};

bool pv_charging; // currently charging, state from pv charger
bool pv_done; // battery fully charged, state from pv charger


uint32_t sleep_offset =0; //time passed since last increment of time(). used for ws80 deepsleep reading time offset from rtc

// Function prototypes
bool setup_flash();
void setup_usb_msc();
DSTATUS disk_status(BYTE pdrv);
DSTATUS disk_initialize(BYTE pdrv);
DRESULT disk_read (BYTE pdrv, BYTE *buff, DWORD sector, UINT count);
DRESULT disk_write (BYTE pdrv, const BYTE *buff, DWORD sector, UINT count);
DRESULT disk_ioctl (BYTE pdrv,BYTE cmd,	void *buff);
bool format_flash();
int32_t msc_read_cb (uint32_t lba, void* buffer, uint32_t bufsize);
int32_t msc_write_cb (uint32_t lba, uint8_t* buffer, uint32_t bufsize);
void msc_flush_cb (void);
bool msc_writable_callback(void);


// Helper ----------------------------------------------------------------------------------------------------------------------

// get current millis since reset, including time spend in deepsleep. Missing time waiting for UART ws80 sensor
uint32_t time(){
  return millis() + sleeptime_cum + sleep_offset;
}

uint16_t get_fanet_id(){
  return UniqueID[0] + ((UniqueID[1])<<8);
}


bool led_status(bool s){
static bool state = false;
bool ret = false;
    if(s){
      pinMode(PIN_STATUSLED,OUTPUT);
      digitalWrite(PIN_STATUSLED, 1);
      if(state){ret = true;} // was on before
      state = true;
    } else {
      state = false;
      digitalWrite(PIN_STATUSLED, 0);
      pinDisable(PIN_STATUSLED);
    }
  return ret;
}


// sets red LED pin to output and turns it on
bool led_error(bool s){
static bool state = false;
bool ret = false;
  if( hw_version >= HW_2_0){
    if(s){
      pinMode(PIN_ERRORLED,OUTPUT);
      digitalWrite(PIN_ERRORLED, 1);
      if(state){ret = true;} // was on before
      state = true;
    } else {
      state = false;;
      digitalWrite(PIN_ERRORLED, 0);
      pinDisable(PIN_ERRORLED);
    }
  } else {
    ret = led_status(s);
  }
  return ret;
}

void i2c_scan(){
  byte error, address;
  int nDevices;
  nDevices = 0;
  for(address = 1; address < 127; address++){
    Wire.beginTransmission(address);
    error = Wire.endTransmission();
 
    if (error == 0){
      DEBUGSER.print("I2C device found at address 0x");
      if (address<16)
        DEBUGSER.print("0");
      DEBUGSER.println(address,HEX);

      if(address == 0x2F){hw_version = HW_1_3;} // only HW1.3 has digipot
 
      nDevices++;
    }
    else if (error==4){
      DEBUGSER.print("Unknown error at address 0x");
      if (address<16)
        DEBUGSER.print("0");
      DEBUGSER.println(address,HEX);
    }    
  }
  if (nDevices == 0){DEBUGSER.println("No I2C devices found\n");}
}


// read solderjumers one and disable pins again
uint8_t read_id(){
  uint8_t id= 0;
  pinMode(PIN_ID0, INPUT_PULLUP);
  pinMode(PIN_ID1, INPUT_PULLUP);

  id &= digitalRead(PIN_ID0);
  id &= digitalRead(PIN_ID1) << 1;

  pinDisable(PIN_ID0);
  pinDisable(PIN_ID1);
  return id;
}

// process line in 'key=value' format and hand to callback function
bool process_line(char * in, int len, bool (*cb)(char*, char*)){
  #define BUFFLEN 127
  char name [BUFFLEN];
  char value [BUFFLEN];
  memset(name,'\0',BUFFLEN);
  memset(value,'\0',BUFFLEN);
  bool literal = false; // 
  char* ptr = name; //start with name filed
  int c = 0; // counter
  int oc= 0; // output counter
  bool cont = true; //continue flag

  while (cont && (c < max(len,BUFFLEN)) && (oc < (BUFFLEN-1))){ // limit to 255 chars per line
    if(in[c] < 127){
      switch (in[c]) {
        case '\r': if(c != 0) {cont = false;} break;
        case '\n': cont = false; break;
        //case '-': cont = false; break; // catches negative temps
        case '>': cont = false; break;
        case '!':  cont = false; break;
        case '#':  cont = false; break;
        case '?':  literal = true; break; // enable literal mode
        case '=':  if(oc && (ptr == name) ){ *(ptr+oc) = '\0'; ptr = value; oc = 0;} break; // switch to value
        case ' ':  if(!literal) {break;} // avoid removing whitespaces from name
        default:   *(ptr+oc) = in[c]; oc++; break; // copy char
      }
    }
    c++;
  }
  if(oc && (ptr == value)){ // value is set
    return cb(name, value);
  }
  
  return false;
}
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
void loop(){

static uint32_t send_active=0; // if > 0, time() last message was send to tx queue, reset to 0 if send is complete
static uint32_t last_settings_check = 0; // timee() ckecked if a settings file is present if settings not read yet sucessfully

// print millis as alive counter
static uint32_t last_call = 0;
static bool s = false;

loopcounter++;

if(last_call && (time()-last_call > 15)){
  if(!s){led_status(0);}
}
if(usb_connected && time()-last_call > 500){
  //log_i("Time: ", time());
  //Serial.println(time());
  Serial1.println(time());
  // Store led states and restore after blink
  s = led_status(1);
  last_call=time();
}

//Serial1.print(sleep_allowed); Serial1.print("\t"); Serial1.println(time());




#ifdef HAS_HEATER
  if(is_heater && (hw_version == HW_1_3)){run_heater();}
#endif

  if(is_baro){read_baro();}
  if(is_gps){read_gps();}

  if(fanet_cooldown_ok() && broadcast_interval_name && ( (time()- last_msg_name) > (broadcast_interval_name* broadcast_scale_factor)) ){ // once a hour
    if(station_name.length() > 1){
      led_status(1);
      send_msg_name(station_name.c_str(),station_name.length());
      log_i("Send name: "); log_i(station_name.c_str()); log_i("\r\n");
      last_fnet_send = time();
      last_msg_name = time();
      send_active = time();
      led_status(0);
    }
  }

  if(fanet_cooldown_ok() && broadcast_interval_weather && ( (time()- last_msg_weather) > (broadcast_interval_weather * broadcast_scale_factor)) ){
    if( allowed_to_send_weather() ){
      send_msg_weather();
      last_fnet_send = time();
      last_msg_weather = time();
      send_active = time();
    } else {
      if(is_wsxx && last_wsxx_data && (time()- last_wsxx_data > 9000)){
        log_e("Wdata not ready. Sleep\r\n");
        sleep_allowed = time() + 1;
        last_wsxx_data = 0;
      }
      
    }
  }
  if(broadcast_interval_info && fanet_cooldown_ok() && ( (time()- last_msg_info) > (broadcast_interval_info * broadcast_scale_factor)) ){
      led_status(1);
      send_msg_info();
      last_fnet_send = time();
      last_msg_info = time();
      send_active = time();
      led_status(0);
  }

  if(send_active){
    if( (time()- send_active > (3500))){
      led_error(1);
      log_i("Send timed out\r\n");
      led_status(0);
      send_active =0;
      sleep_allowed = time() + (1);
      radio_phy->sleep();
      delay(10);
      led_error(0);
    }

    if(transmittedFlag){
      transmittedFlag = false;
      //log_i("Send complete\r\n");
      send_active = 0;
      sleep_allowed = time() + (1);
      radio_phy->finishTransmit();
      radio_phy->sleep();
    }
  }

// Check if everything is done --> sleep
  if(!send_active && sleep_allowed && (time() > sleep_allowed) && (!usb_connected || test_with_usb) && (time() > 2500)){ // allow sleep after 2500 ms to get a change to detect usb connected
    go_sleep();
  }

  if(!settings_ok){ // Settings not ok. Try few times, then sleep
    if(!sleep_allowed){ 
      sleep_allowed = time() + 180000UL; // Sleep after 3 minutes
    }
    if(time()- last_settings_check > 15000){
      last_settings_check = time();
      log_e("\r\nFailed to obtain settings from file. Trying again\r\n");
      settings_ok = parse_file(SETTINGSFILE);
      if(settings_ok){ 
        NVIC_SystemReset();      // processor software reset
        }
    }
  }

  // during Dev
  if(usb_connected){
    if(test_with_usb){read_wsxx();} // to simulate normal behavior without sleep read and parse data from serial port
    else {forward_wsxx_serial();} // otherwise just forward the data
    read_serial_cmd(); // read setting values from serial for testing
    if(!no_sleep && !test_with_usb && (time() > 15UL*60UL*1000UL)){
      log_i("Restart\r\n");
      log_flush();
      usb_connected = false;
      NVIC_SystemReset();
      } // keep usb alive for 15 min
  }

  if((time() > 5UL*60UL*1000UL)){ // trun off error LED after 5minutes to save energy if an error occures with no one around
    led_error(0);
  }

  if(use_wdt){
    wdt_reset();
  }
  
}


// Flash ----------------------------------------------------------------------------------------------------------------------
#define DISK_LABEL  "Breezedude"
FATFS elmchamFatfs;

DSTATUS disk_status(BYTE pdrv){
  (void) pdrv;
	return 0;
}

DSTATUS disk_initialize(BYTE pdrv){
  (void) pdrv;
	return 0;
}

DRESULT disk_read (BYTE pdrv, BYTE *buff, DWORD sector, UINT count){
  (void) pdrv;
	return flash.readBlocks(sector, buff, count) ? RES_OK : RES_ERROR;
}

DRESULT disk_write (BYTE pdrv, const BYTE *buff, DWORD sector, UINT count){
  (void) pdrv;
  return flash.writeBlocks(sector, buff, count) ? RES_OK : RES_ERROR;
}

DRESULT disk_ioctl (BYTE pdrv,BYTE cmd,	void *buff){
  (void) pdrv;
  switch ( cmd ){
    case CTRL_SYNC:
      flash.syncBlocks();
      return RES_OK;
    case GET_SECTOR_COUNT:
      *((DWORD*) buff) = flash.size()/512;
      return RES_OK;
    case GET_SECTOR_SIZE:
      *((WORD*) buff) = 512;
      return RES_OK;
    case GET_BLOCK_SIZE:
      *((DWORD*) buff) = 8;    // erase block size in units of sector size
      return RES_OK;
    default:
      return RES_PARERR;
  }
}

bool format_flash(){
  //return false;
  uint8_t workbuf[1024]; // Working buffer for f_fdisk function. 4096->1024, maybe we run out of heap?
  FRESULT r = f_mkfs12("", FM_FAT, 0, workbuf, sizeof(workbuf));
  if (r != FR_OK) {
     log_i("Error, f_mkfs failed with error code: ", r);
    return false;
  }
  r = f_mount(&elmchamFatfs, "0:", 1);   // mount to set disk label
  if (r != FR_OK) {
     //log_i("Error, f_mount failed with error code: ", r);
    return false;
  }
   // log_i("Setting disk label to: "); log_i(DISK_LABEL); log_i("\r\n");
  r = f_setlabel(DISK_LABEL);
  if (r != FR_OK) {
     //log_i("Error, f_setlabel failed with error code: ", r);
    return false;
  }
  f_unmount("0:"); // unmount
  flash.syncBlocks(); // sync to make sure all data is written to flash
  return true;
}

int32_t msc_read_cb (uint32_t lba, void* buffer, uint32_t bufsize){
  //Serial.printf("Reading at %d with size %d\n",lba,bufsize);
  my_internal_storage.read(lba*DISK_BLOCK_SIZE, buffer, bufsize);
  return bufsize;
}

// Callback invoked when received WRITE10 command.
// Process data in buffer to disk's storage and 
// return number of written bytes (must be multiple of block size)
int32_t msc_write_cb (uint32_t lba, uint8_t* buffer, uint32_t bufsize){
  //Serial.printf("Writing at %d with size %d\n",lba,bufsize);
  // Erase should be done before every writing to the flash
  my_internal_storage.erase(lba*DISK_BLOCK_SIZE, bufsize);
  // Write to the flash
  my_internal_storage.write(lba*DISK_BLOCK_SIZE, buffer, bufsize);
  return bufsize;
}

// Callback invoked when WRITE10 command is completed (status received and accepted by host).
// used to flush any pending cache / sync with flash
void msc_flush_cb (void){
  my_internal_storage.flush_buffer();
}
// Invoked to check if device is writable as part of SCSI WRITE10
// Default mode is writable
bool msc_writable_callback(void){
  // true for writable, false for read-only
  if(!usb_connected){
    log_i("USB Connected: ", time());
  }
  usb_connected = true;
  return true;
}

void setup_usb_msc(){
  //log_i("USB MSC Setup\n");
    // Set disk vendor id, product id and revision with string up to 8, 16, 4 characters respectively
  usb_msc.setID("BrezeDu", "Mass Storage", "1.0");
   
  // Set disk size
  uint32_t DISK_BLOCK_NUM = my_internal_storage.get_flash_size()/DISK_BLOCK_SIZE;
  //log_i("DISK_BLOCK_NUM: ", DISK_BLOCK_NUM);
  usb_msc.setCapacity(DISK_BLOCK_NUM-1, DISK_BLOCK_SIZE);

  // Set callbacks
  usb_msc.setReadWriteCallback(msc_read_cb, msc_write_cb, msc_flush_cb);
  usb_msc.setWritableCallback(msc_writable_callback);

  // Set Lun ready (internal flash is always ready)
  usb_msc.setUnitReady(true);
  usb_msc.begin();

  Serial.begin(115200); // USB Serial
  //while ( !Serial ) delay(10);   // wait for native usb
  delay(10);
}
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

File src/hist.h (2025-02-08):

#pragma once
#include <Arduino.h>
#include "logging.h"

extern uint32_t time();


// Gust History, for data transmission
typedef struct g{
  uint32_t time;
  uint32_t gust;
  uint32_t wind;
  int dir_raw;
} WindSample;


#define HISTORY_INTERVAL 30*1000 // 30s 3600*1000 // 1h
#define HISTORY_LEN 15*24 // in hours, 15 days

#define WIND_AGE 1000*30 // 30s history
#define GUST_AGE 1000*60*10 // 10 min history
#define WIND_HIST_STEP 1000*4 //ms history slots, 22 sek
#define WIND_HIST_LEN 150 // number so slots. should match GUST_AGE / GUST_HIST_STEP
WindSample wind_history[WIND_HIST_LEN]; // gust ringbuffer
uint8_t wind_hist_pos = 0; // current position in ringbuffer

// Data histroy, mainly for heater control
typedef struct h{
  bool set = false;
  int8_t wind;
  int8_t temp;
  int8_t humd;
  int8_t light;
  int8_t batt;
  bool pv_charging;
  bool pv_done;
} History;

History history[HISTORY_LEN];
int hist_count =0;
uint32_t last_history =0;


void check_wind_hist_bin(){
  if( wind_history[wind_hist_pos].time && (time() - wind_history[wind_hist_pos].time) > WIND_HIST_STEP){
    // copy old values if there is an read error from serial to avoid 0 to be included in average
    uint32_t g = wind_history[wind_hist_pos].gust;
    uint32_t w = wind_history[wind_hist_pos].wind;
    int d = wind_history[wind_hist_pos].dir_raw;

    wind_hist_pos++;
    if(wind_hist_pos == WIND_HIST_LEN){
      wind_hist_pos = 0;
    }
    // reset values if already set (overwrite ringbuffer)
    wind_history[wind_hist_pos].gust = g;
    wind_history[wind_hist_pos].wind = w;
    wind_history[wind_hist_pos].dir_raw = d;
    wind_history[wind_hist_pos].time = 0; // will be set by every add_... 
  }
}

// Adds/updates wind value in ringbuffer
void add_wind_history_wind(float val_wind){
  check_wind_hist_bin(); // Agg slot time is over, switch to next
  wind_history[wind_hist_pos].wind = val_wind*10;
  wind_history[wind_hist_pos].time = time();
}

// Adds/updates gust value in ringbuffer
void add_wind_history_gust(float val_gust){
  check_wind_hist_bin(); // Agg slot time is over, switch to next
  wind_history[wind_hist_pos].gust = abs(val_gust)*10;
  wind_history[wind_hist_pos].time = time();
}

// Adds/updates dir value in ringbuffer
void add_wind_history_dir(int val_dir){
  check_wind_hist_bin(); // Agg slot time is over, switch to next
  wind_history[wind_hist_pos].dir_raw = val_dir;
  wind_history[wind_hist_pos].time = time();
}

// gets the highest wind value in ringbuffer, not older than age
WindSample get_wind_from_hist(uint32_t age){
  WindSample ret = {0,0,0,0};

  float y_part = 0;
  float x_part = 0;
  int samplecount =0;

  uint8_t p = wind_hist_pos;
  for( int i = 0; i < WIND_HIST_LEN; i++){
    if(p == WIND_HIST_LEN){
      p -= WIND_HIST_LEN;
    }
    if( ( wind_history[p].time && (time()- wind_history[p].time) < age)){
      ret.wind += wind_history[p].wind;
      ret.gust += wind_history[p].gust;
      x_part += cos (wind_history[p].dir_raw * M_PI / 180);
      y_part += sin (wind_history[p].dir_raw * M_PI / 180);
      samplecount++;
    }
    p++;
  }
  if(samplecount > 0){
    ret.dir_raw = atan2 (y_part / samplecount, x_part / samplecount) * 180 / M_PI;
    if(ret.dir_raw <0){ ret.dir_raw +=360;}

   // log_i("Sum Wind: ", ret.wind);
   // log_i("Sum Gust: ", ret.gust);
   // log_i("Samples: ", samplecount);
    ret.wind /= samplecount;
    ret.gust /= samplecount;
  } else {
    //log_e("Samplecount is 0\r\n");
  }
  return ret;
}

void insert_sorted(uint32_t* arr, int arrlen, uint32_t value){
    if (value <= arr[arrlen - 1]) {
        return; // value too small, skip
    }
    int i = 0;
   // while (pos < arrlen && value < arr[pos]) {
   //     pos++; // Find position to insert the value.
   // }
    // Shift elements down to make room for the new value.
    for (i = arrlen - 1; (i >= 0 && arr[i] < value); i--) {
        arr[i + 1] = arr[i]; // Verschiebe Elemente nach rechts
    }
   // if (pos < arrlen) {
   //     memmove(&arr[pos + 1], &arr[pos], (arrlen - 1 - pos) * sizeof(uint32_t));
   // }
    arr[i+1] = value;
}

float get_gust_from_hist(uint32_t age){
  #define GUSTBUFFERLEN 7
  uint32_t ret[GUSTBUFFERLEN] = {0,0,0,0,0,0,0};
  uint8_t p = wind_hist_pos;
  for( int i = 0; i < WIND_HIST_LEN; i++){
    if(p == WIND_HIST_LEN){
      p -= WIND_HIST_LEN;
    }
    // check the hisftory for gust values within the set gust age.
    if(( wind_history[p].time && (time()- wind_history[p].time) < age)){
      //printf("age: %lu, value: %0.2f\n", (time()- wind_history[p].time), (float)(wind_history[p].gust)/10.0 );
      insert_sorted(ret, GUSTBUFFERLEN, wind_history[p].gust);
    }
    p++;
  }
  //printf("0: %lu 1: %lu 2: %lu 3: %lu 4: %lu \n", ret[0], ret[1], ret[2], ret[3], ret[4] );
  return ret[4]/10.0; // return 5th highest value to avoid sending a reading error or one time high value
}



// History ----------------------------------------------------------------------------------------------------------------------
// save history value if time is ready  for a new one
void save_history(float wind_speed, float temperature, int humidity, int light_lux, float batt_volt, bool pv_charging, bool pv_done){
  static uint32_t last_history = 0;
  if(time() - last_history > HISTORY_INTERVAL){
    last_history = time();
    hist_count++;
    if(hist_count == HISTORY_LEN){hist_count = 0;}
    log_i("Saving Hist no: ", hist_count);
    history[hist_count].set = true;
    history[hist_count].wind = wind_speed*10;
    history[hist_count].temp = temperature;
    history[hist_count].humd = humidity;
    history[hist_count].light = light_lux/100;
    history[hist_count].batt = (batt_volt-2)*100;
    history[hist_count].pv_charging = pv_charging;
    history[hist_count].pv_done = pv_done;
  }
}

// calc sum of light sensor reading in n last ringbuffer entries
uint32_t history_sum_light(int len){
  int sum = 0;
  for (int i=0; i<len; i++){
    int hpos = hist_count-i;
    if(hpos <0){hpos += HISTORY_LEN;} // get pos of ringbuffer

    if(history[hpos].set){
      sum += history[hpos].light;
      if(sum > 2147480000){break;} // abort if very high value
    }
  }
  return sum;
}

// calc sum of wind speed reading in n last ringbuffer entries
uint32_t history_sum_wind(int len){
  int sum = 0;
  for (int i=0; i<len; i++){
    int hpos = hist_count-i;
    if(hpos <0){hpos += HISTORY_LEN;} // get pos of ringbuffer

    if(history[hpos].set){
      sum += history[hpos].wind;
      if(sum > 2147480000){break;} // abort if very high value
    }
  }
  return sum;
}

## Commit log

2024-04-11 fix whitespace in name, add support for SPL06 barometer
    [main.cpp]
2024-04-12 continuous sampling of ws80 while in deepsleep. added short term wind history for averaging and better gust tracking
    [main.cpp]
2024-12-27 mini V2.0
    [breezedude_mini.kicad_pcb, breezedude_mini.kicad_sch, ogn_wind_1.4.brd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]
2025-01-03 v2.1. fixed p-fet, added vollgo cc68, vertical SMA
    [breezedude_mini.kicad_pcb, breezedude_mini.kicad_sch]
2025-01-28 0.4. moved to radiolib, added some debugging features, more baro supported, added I2C display
2025-05-04 mini V2.2
    [breezedude_mini.kicad_pcb, breezedude_mini.kicad_sch]
2025-05-06 add support for HP203B pressure sensor

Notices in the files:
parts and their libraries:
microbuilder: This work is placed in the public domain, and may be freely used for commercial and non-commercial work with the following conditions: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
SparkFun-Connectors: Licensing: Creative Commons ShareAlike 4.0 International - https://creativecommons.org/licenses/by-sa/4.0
